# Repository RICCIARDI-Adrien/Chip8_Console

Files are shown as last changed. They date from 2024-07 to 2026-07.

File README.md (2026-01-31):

# Chip-8 Console

A Chip-8/SuperChip-8 console powered by a 8-bit PIC18 microcontroller.

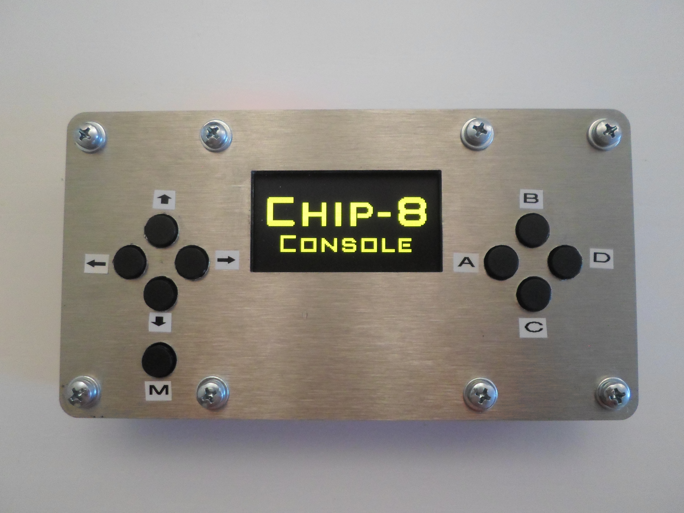
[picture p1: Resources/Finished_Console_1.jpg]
Console displaying the boot logo


## Specifications

* Microchip PIC18F27K42 8-bit microcontroller
* 64 MHz, giving a processing speed of up to 16 MIPS
* 8 KB of on-chip static RAM
* 128x64 pixels monochrome OLED display (Waveshare 2.42inch OLED Display Module)
* SD card interface to store games and files
* Powered by 2x AA batteries
* 8 keys usable with the Chip-8 interpreter, 1 menu key, 1 power-supply switch
* Monotone buzzer

## Dimensions

* Length : 175 mm
* Width : 95 mm
* Depth : 38 mm (including the adhesive feet)
* Weight : 1200 g (including the batteries and the SD card)

## Hardware

Display module :
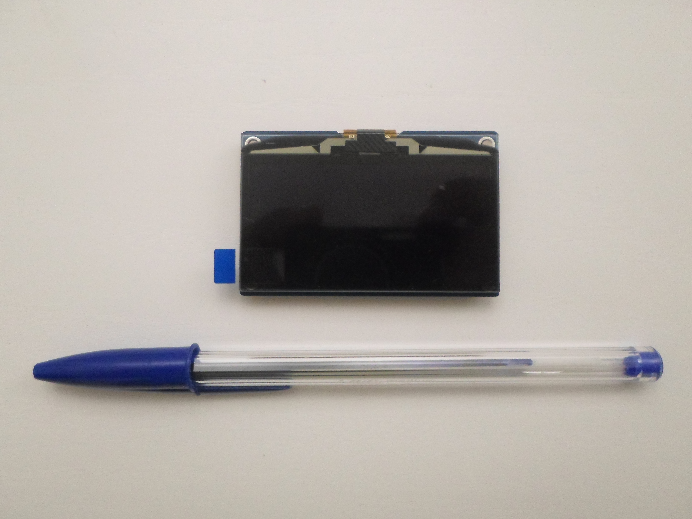
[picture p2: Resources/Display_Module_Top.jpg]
Display module front view

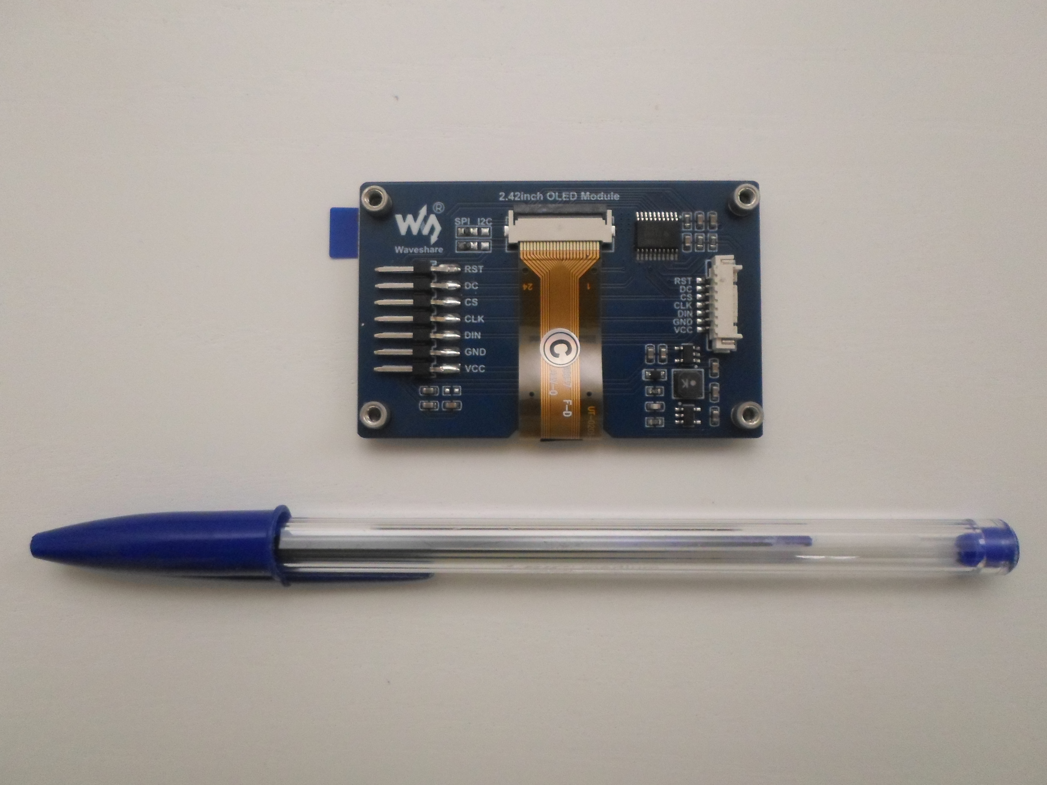
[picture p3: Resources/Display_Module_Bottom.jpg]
Display module bottom view


Bare PCB :
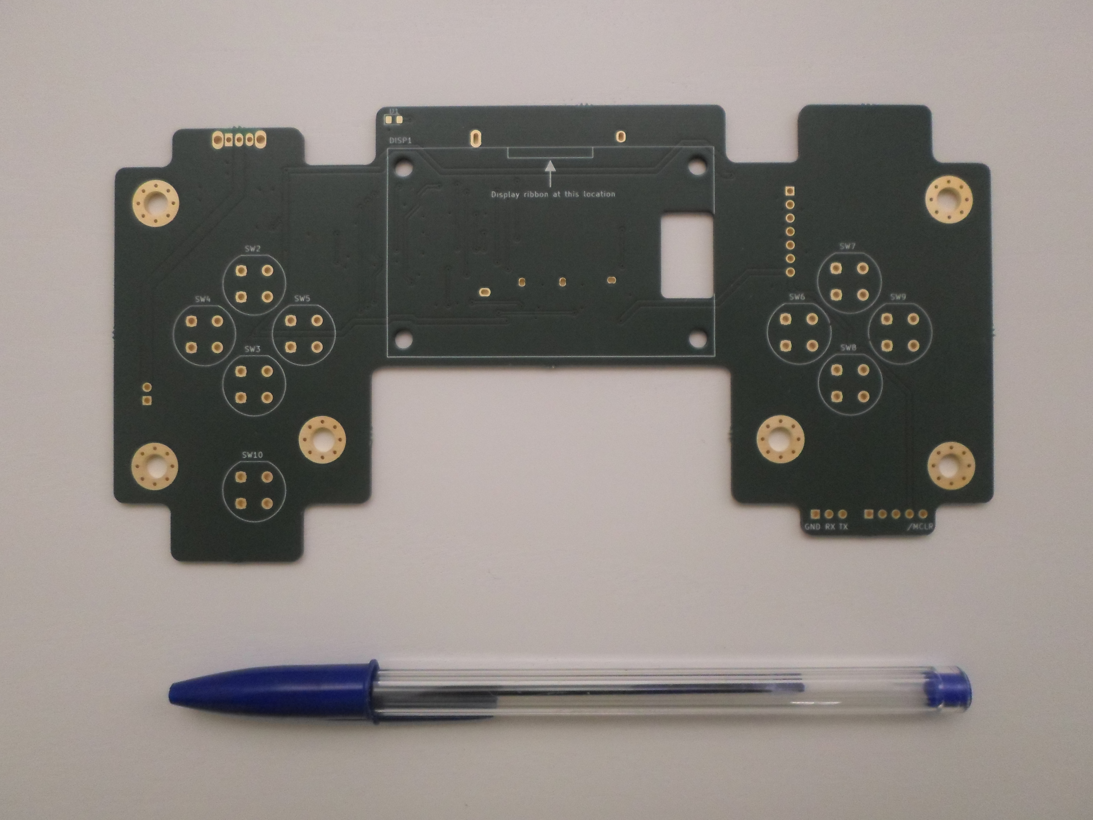
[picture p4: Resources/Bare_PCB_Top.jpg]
Bare PCB front view

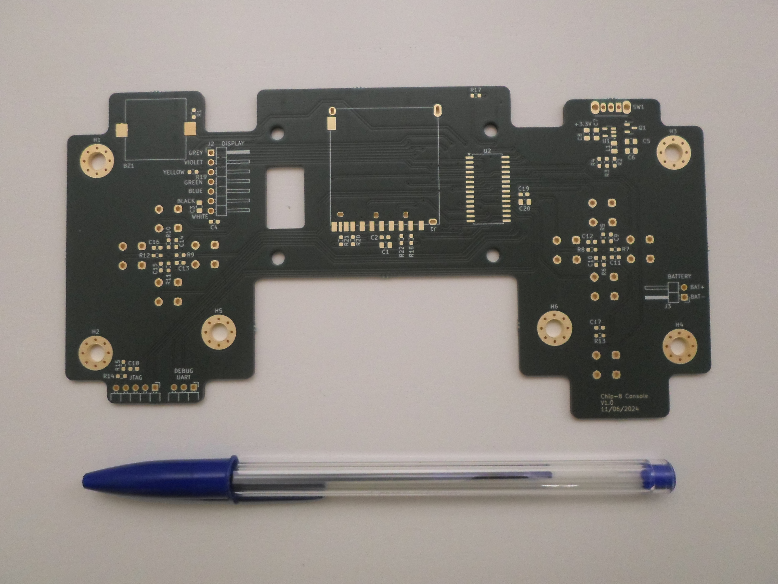
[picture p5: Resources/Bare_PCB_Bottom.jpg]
Bare PCB bottom view


Assembled PCB :
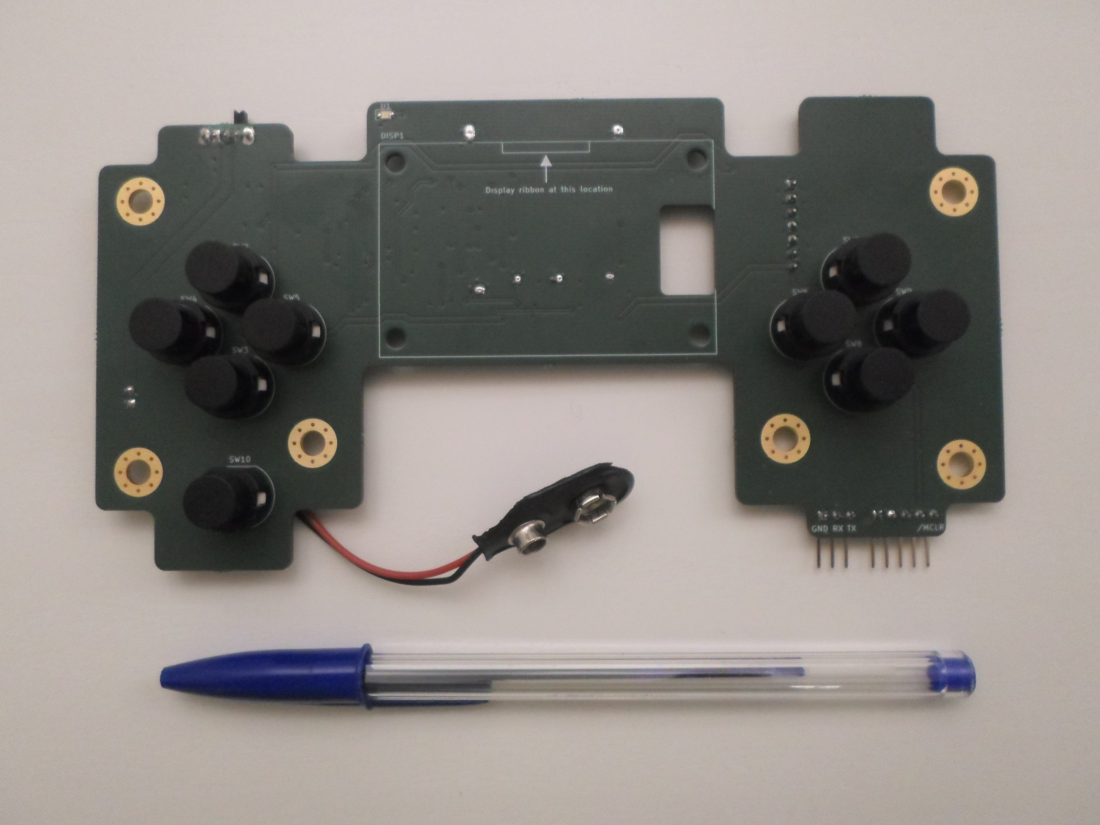
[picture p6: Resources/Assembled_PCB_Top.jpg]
Assembled PCB front view

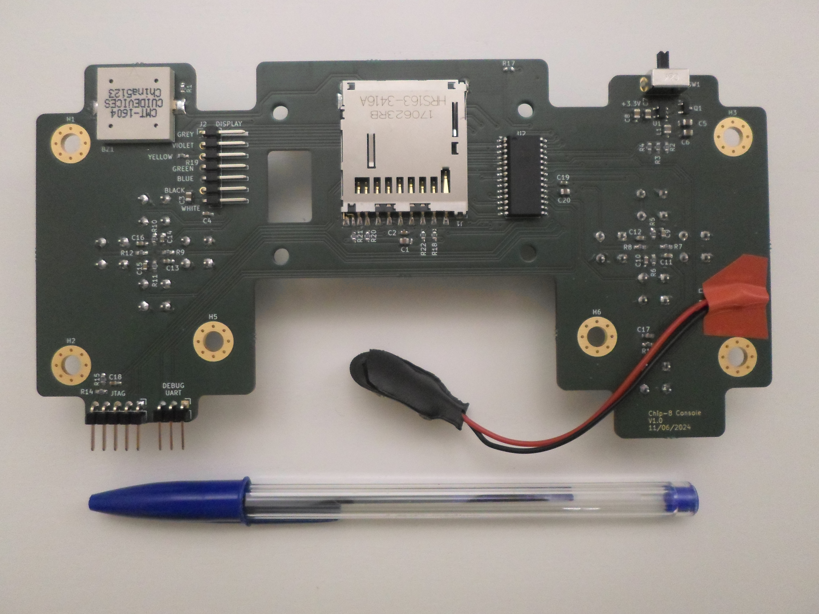
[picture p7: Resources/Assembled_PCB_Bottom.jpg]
Assembled PCB bottom view


Assembled PCB with the display module screwed and connected :
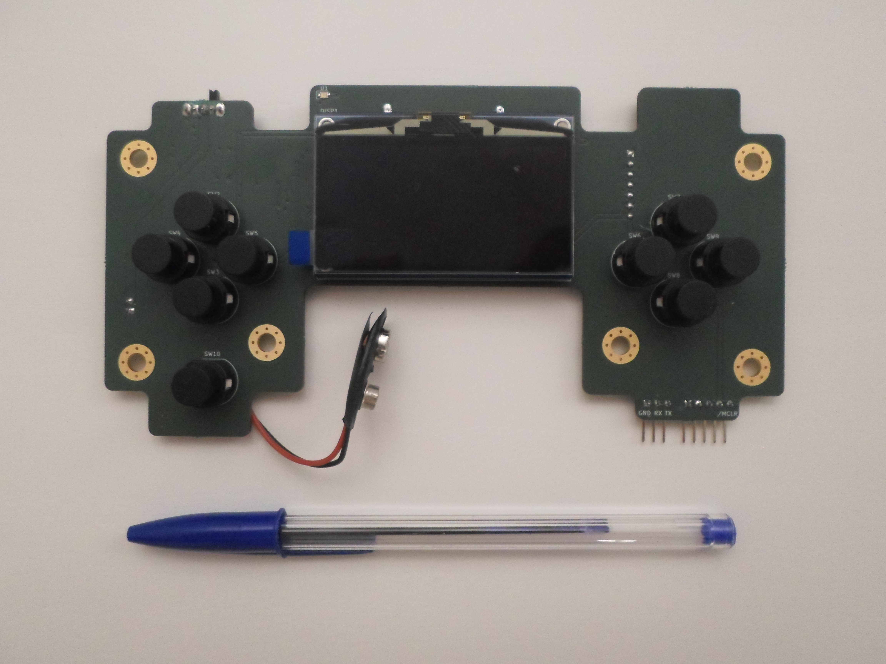
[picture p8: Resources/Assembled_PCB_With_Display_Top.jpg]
Assembled PCB with display front view

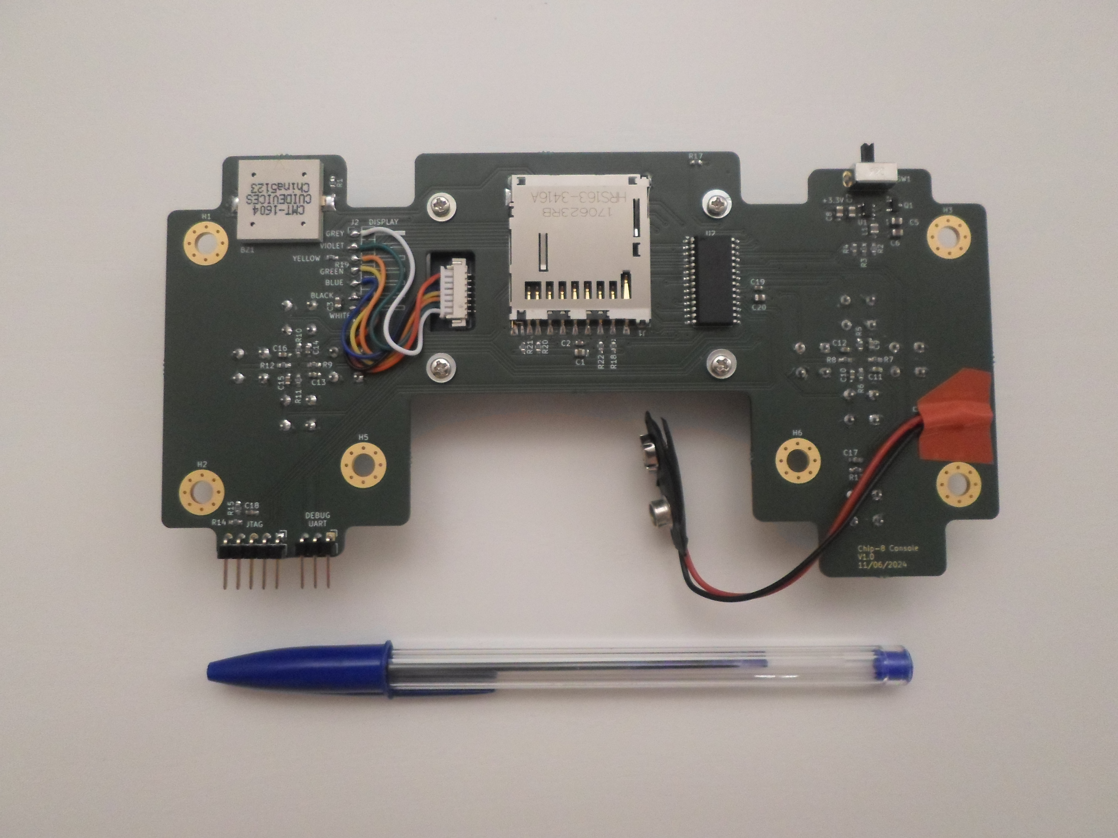
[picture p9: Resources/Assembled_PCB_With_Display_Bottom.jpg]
Assembled PCB with display bottom view


## Casing

The casing is made of two laser-cut metal plates. They are both 4 mm thick and made of stainless 304 steel.  
The metal spacers are 20 mm high. The reference used here is `970200471` from Würth Elektronik.  

Casing plates :
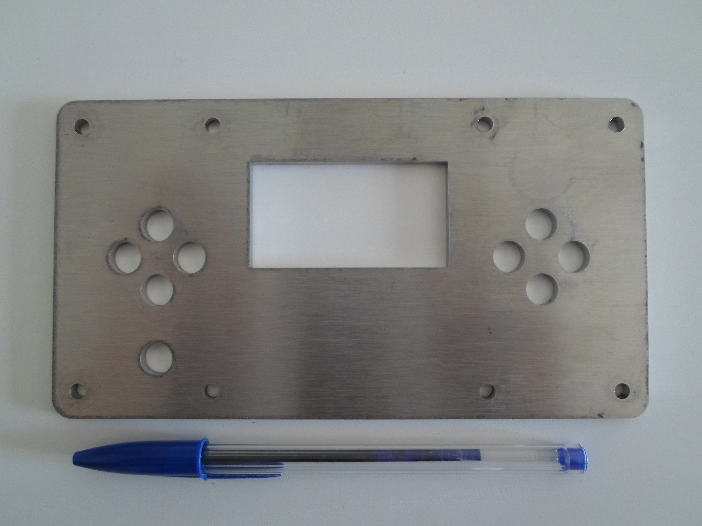
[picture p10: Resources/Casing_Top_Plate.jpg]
Casing top plate

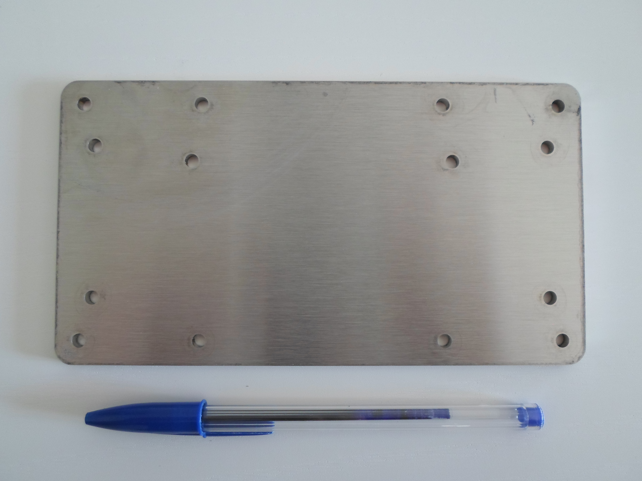
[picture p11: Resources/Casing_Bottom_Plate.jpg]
Casing bottom plate


Bottom plate with screws :
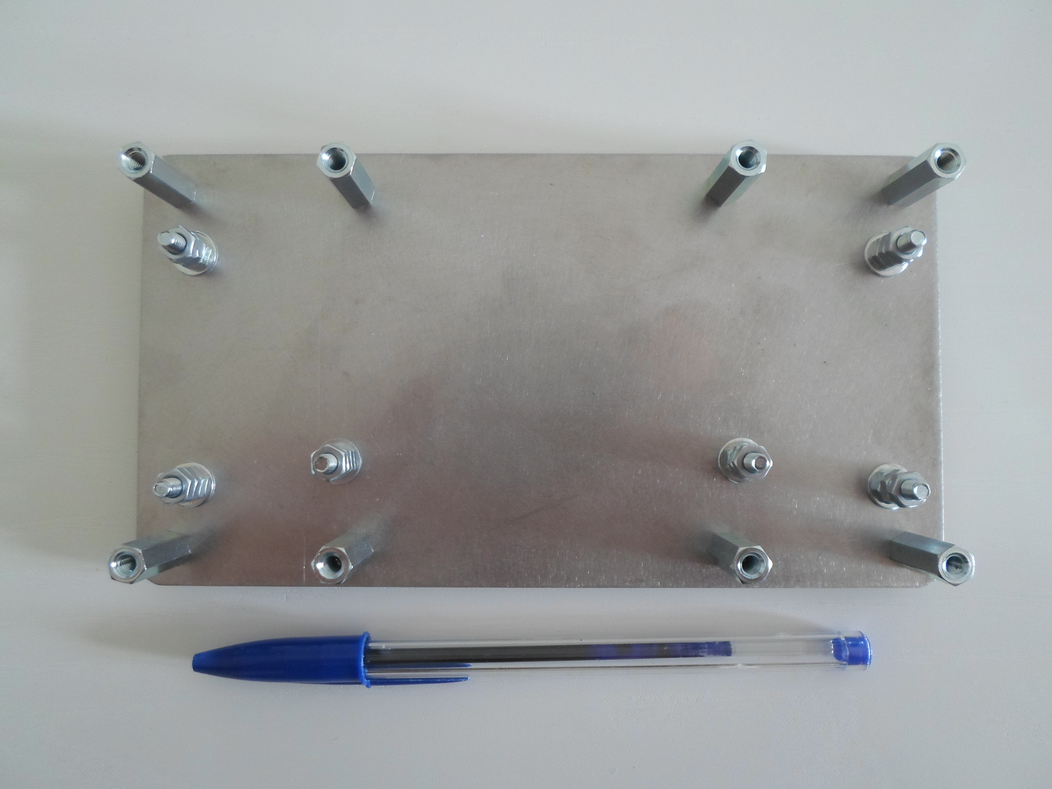
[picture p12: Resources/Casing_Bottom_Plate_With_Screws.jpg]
Casing bottom plate with screws


Bottom plate with screwed PCB :
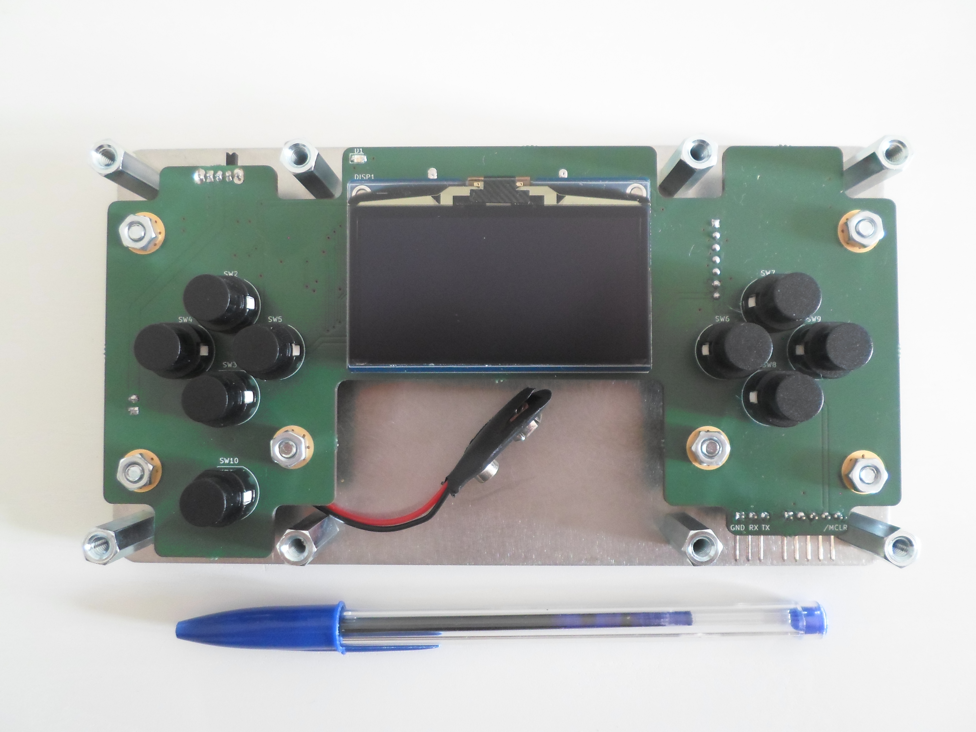
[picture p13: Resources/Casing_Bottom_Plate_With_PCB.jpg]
Casing bottom plate with PCB


Fully assembled console :
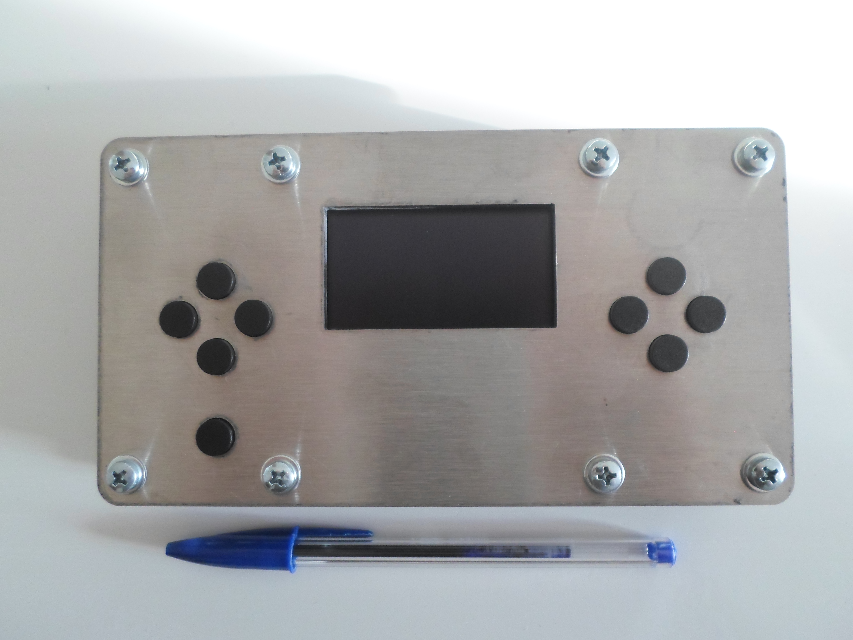
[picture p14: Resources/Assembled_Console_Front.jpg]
Assembled console front

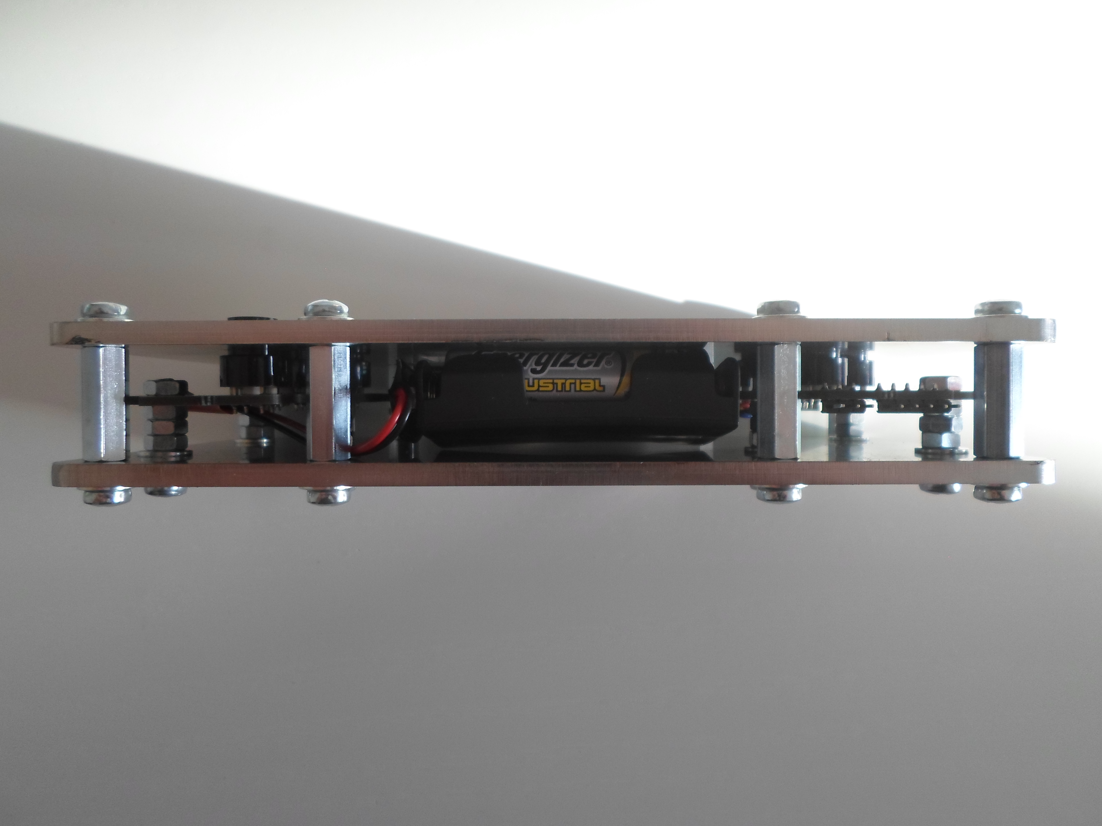
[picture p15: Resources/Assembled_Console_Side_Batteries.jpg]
Assembled console batteries side


## Battery pack hatch

The hatch is made of PCB FR4. The hatch does not require to be as strong as the console casing and the FR4 is a good material to cut complex shapes into.

The hatch is cut as a PCB panel containing all the required parts :
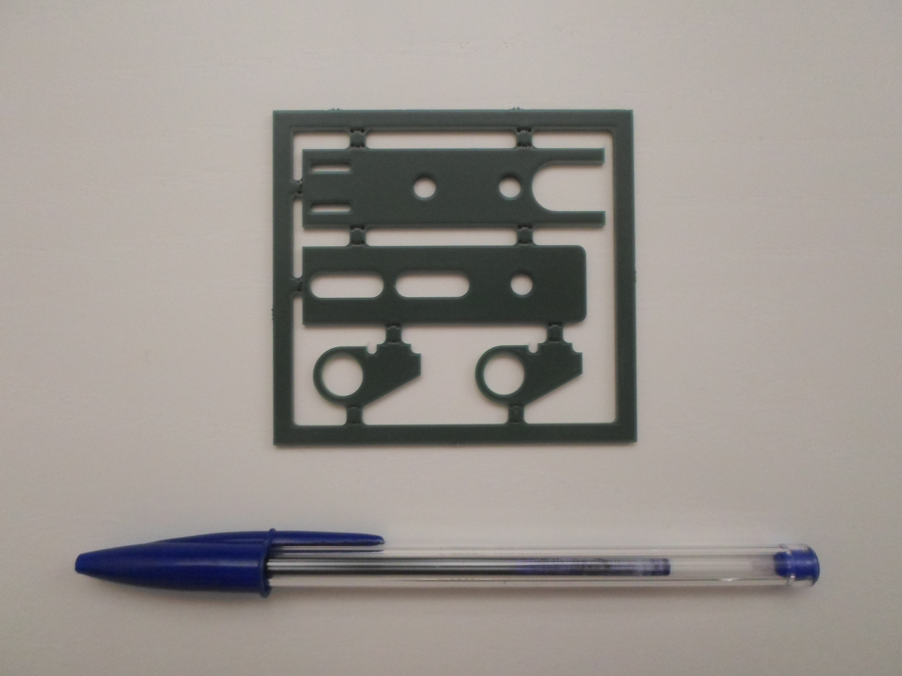
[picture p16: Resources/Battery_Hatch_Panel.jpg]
Battery hatch panel


The first assembly step is to glue the hinges :
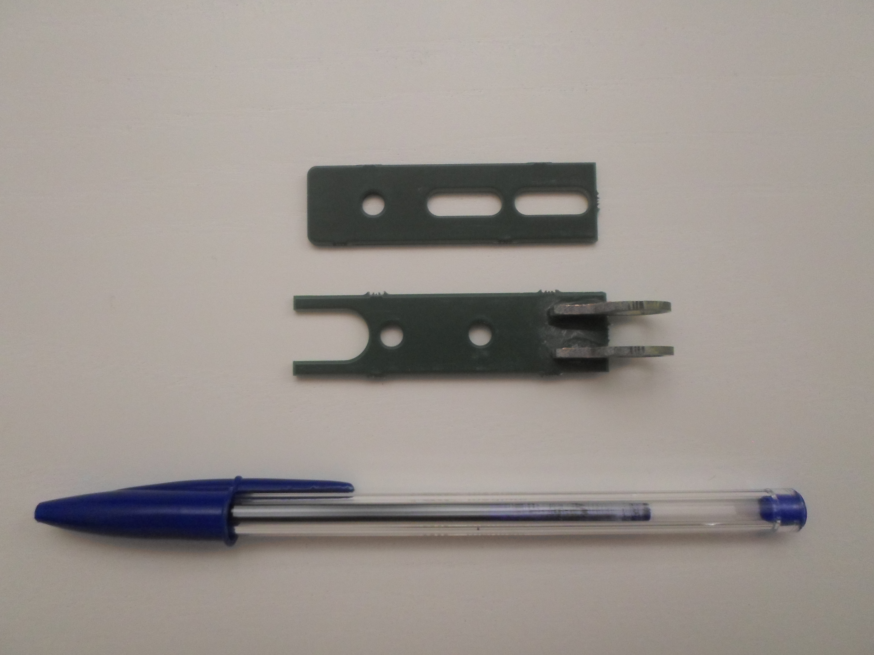
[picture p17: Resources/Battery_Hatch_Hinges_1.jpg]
Battery hatch hinges 1

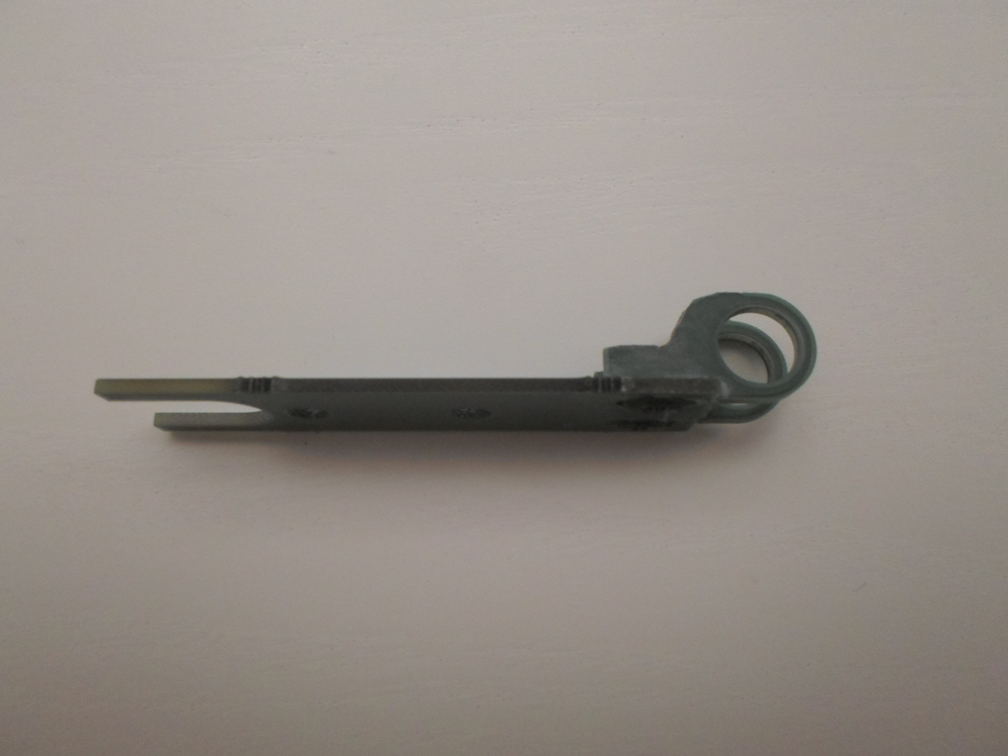
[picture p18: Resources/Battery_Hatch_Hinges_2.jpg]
Battery hatch hinges 2

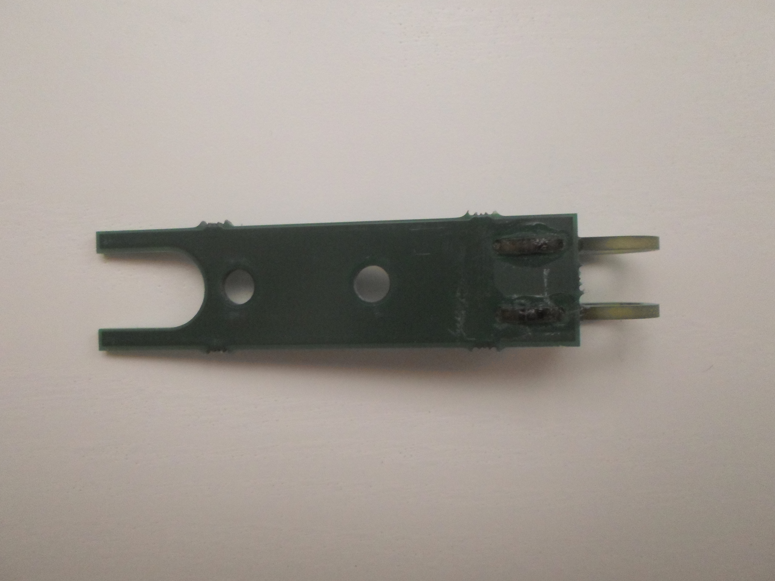
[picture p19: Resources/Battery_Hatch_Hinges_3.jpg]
Battery hatch hinges 3

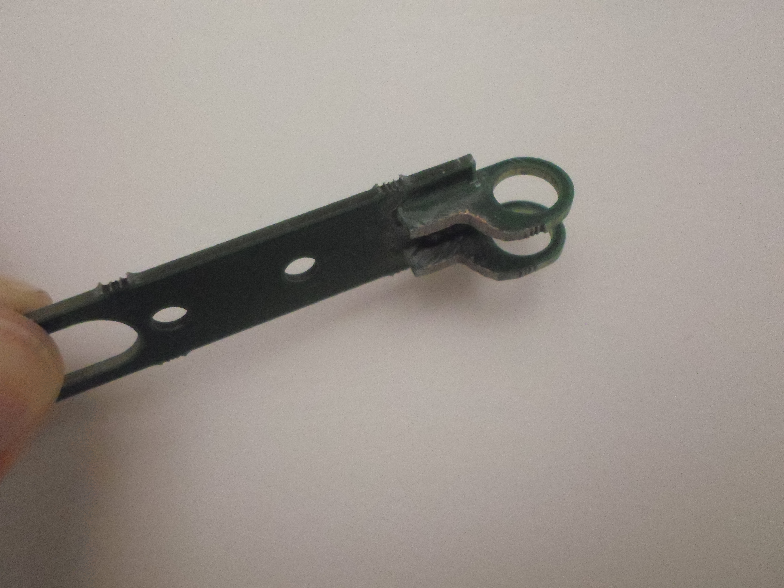
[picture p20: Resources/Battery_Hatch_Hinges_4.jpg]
Battery hatch hinges 4


The second step is to screw the sliding part, and also the bolt used to manipulate the hatch slider :
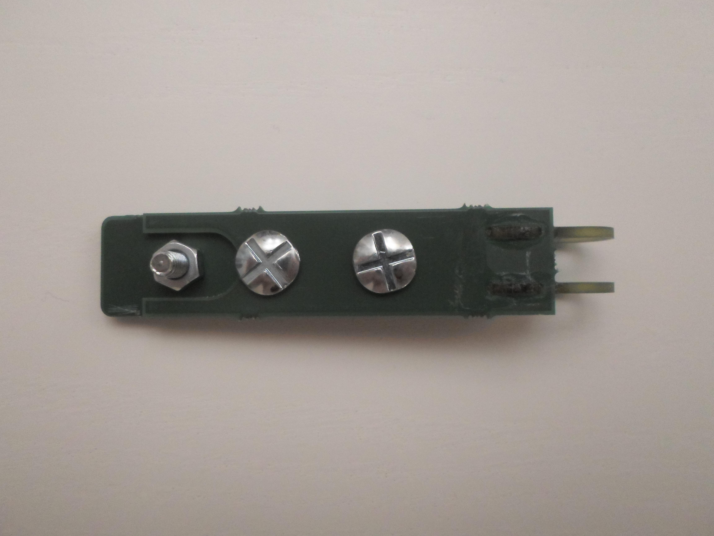
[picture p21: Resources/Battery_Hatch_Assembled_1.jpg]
Battery hatch assembled 1

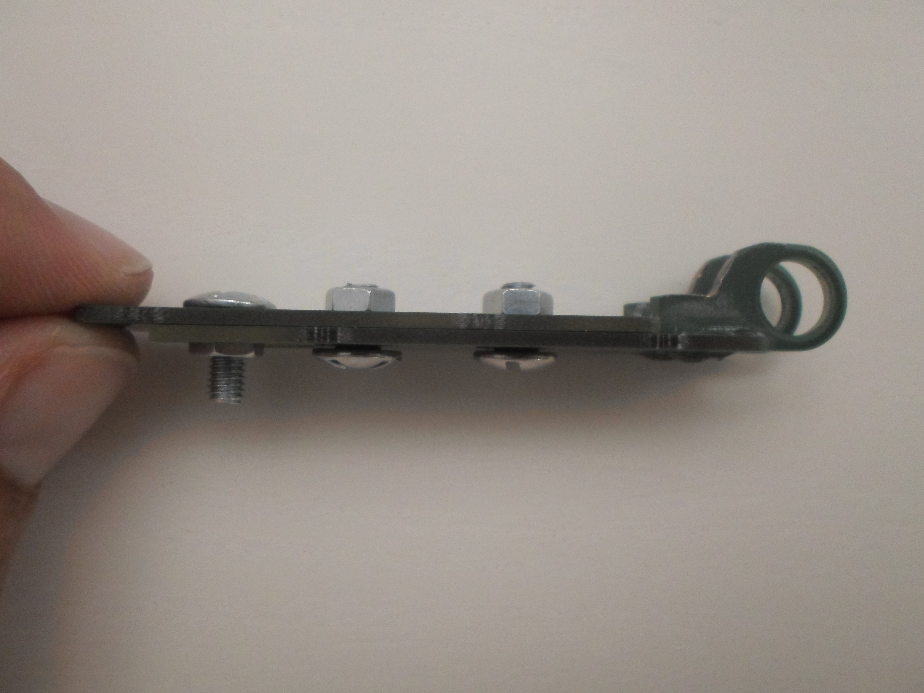
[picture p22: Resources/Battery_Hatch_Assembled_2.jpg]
Battery hatch assembled 2

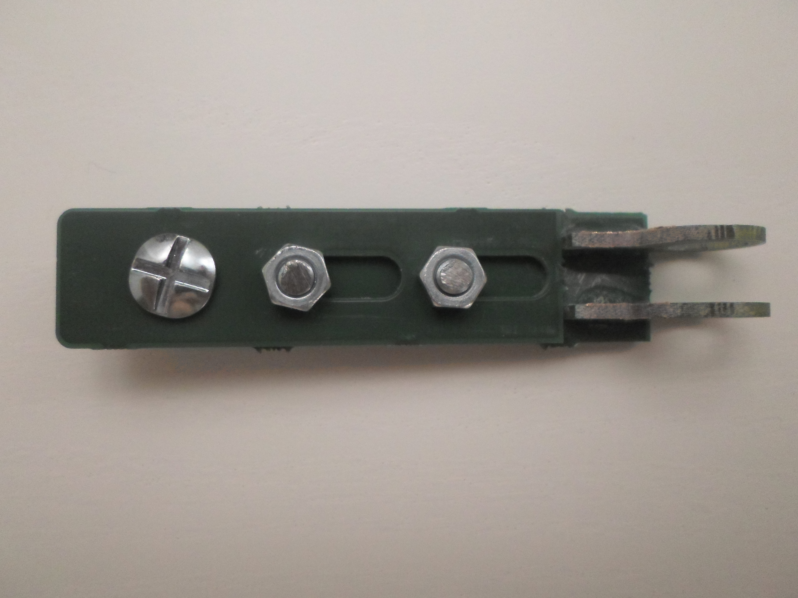
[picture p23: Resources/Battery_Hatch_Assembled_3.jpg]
Battery hatch assembled 3


There is not enough room to use Nyloc nuts, so normal nuts are used and held in place with threadlocker.  
The tightening of these bolts allows the slider to slide with a little force, so the hatch can't open alone.
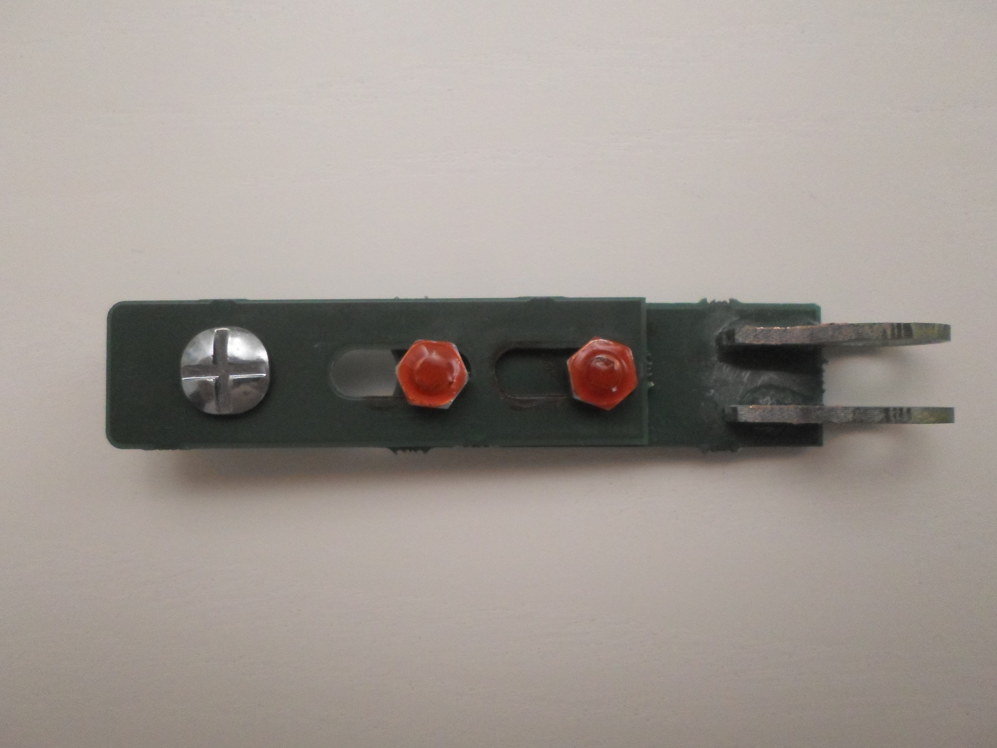
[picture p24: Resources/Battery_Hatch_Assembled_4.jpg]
Battery hatch assembled 4


The strike is made of a piece of PCB coming from the panel edge that is inserted by force between the two metal plates :
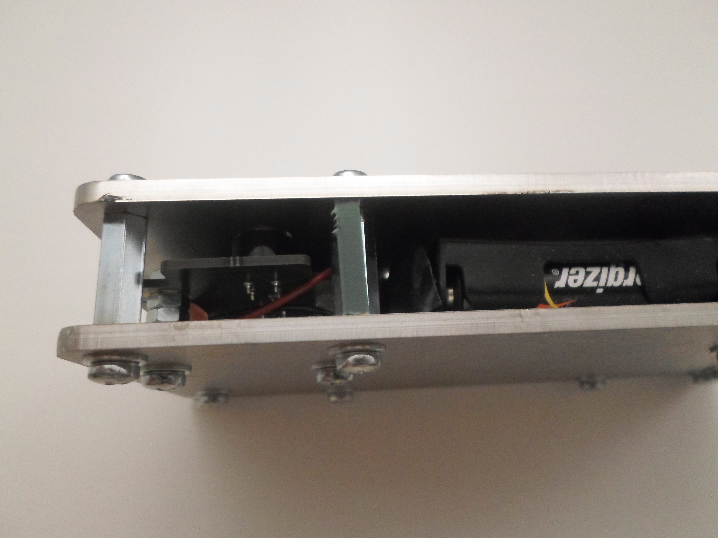
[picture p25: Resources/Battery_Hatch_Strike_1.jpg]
Battery hatch strike 1

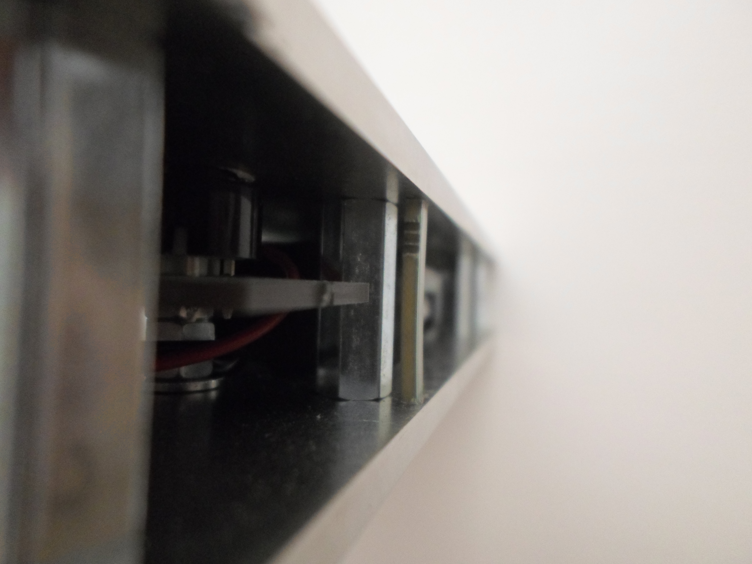
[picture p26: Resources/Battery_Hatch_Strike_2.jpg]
Battery hatch strike 2

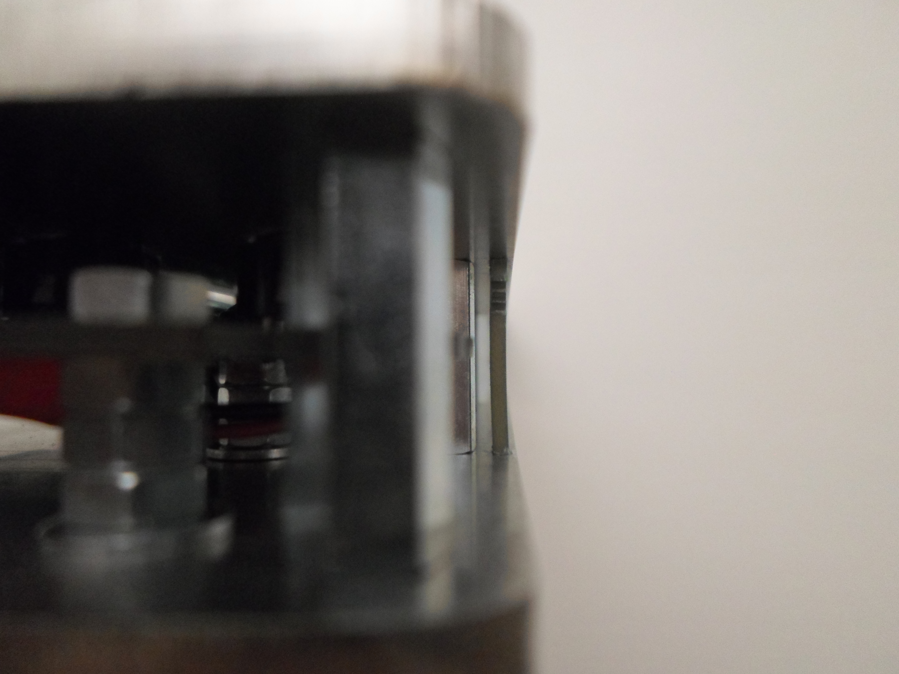
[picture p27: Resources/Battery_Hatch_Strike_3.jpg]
Battery hatch strike 3


Now the hatch can be assembled onto the console.  
Locked hatch :
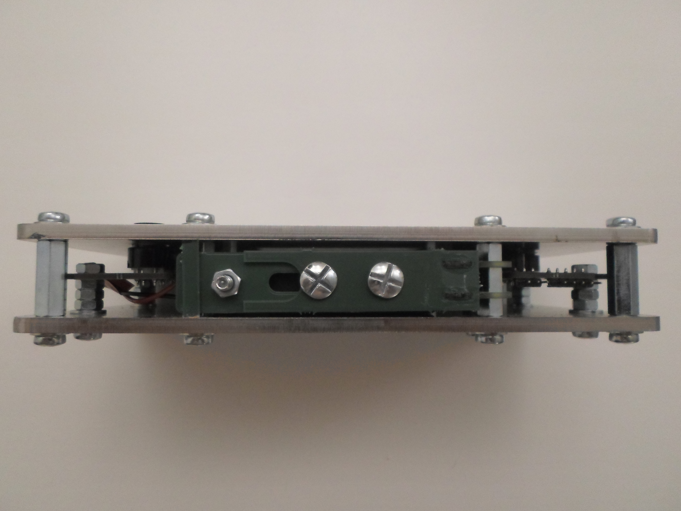
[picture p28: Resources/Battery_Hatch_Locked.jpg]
Battery hatch locked


Unlocked hatch :
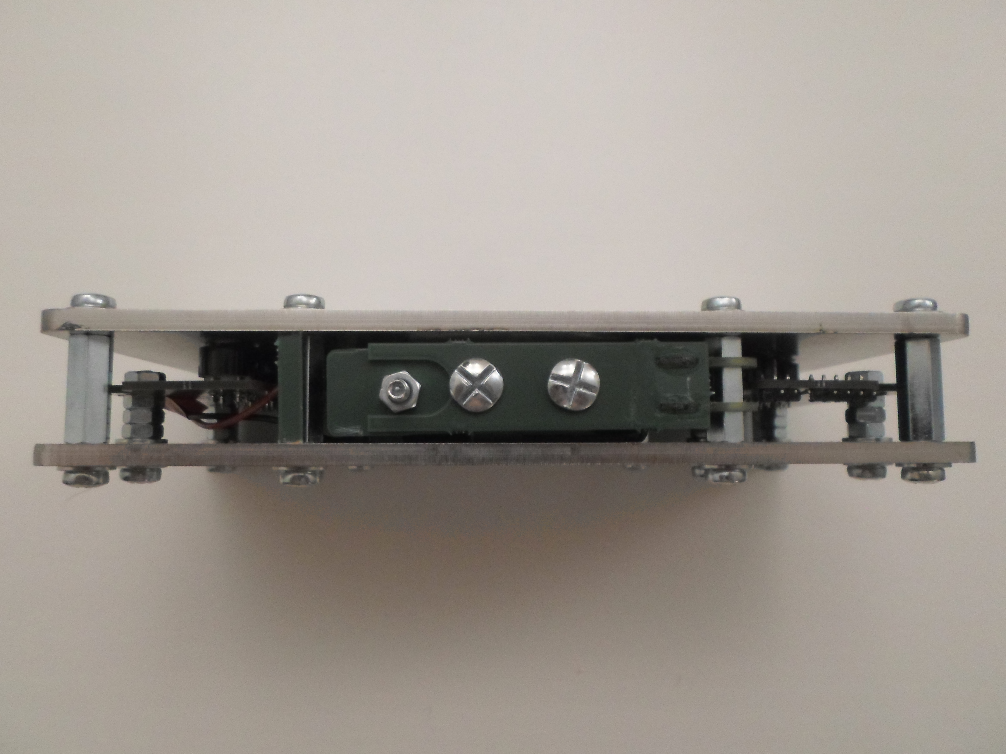
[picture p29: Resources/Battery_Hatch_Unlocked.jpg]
Battery hatch unlocked


Opened hatch :
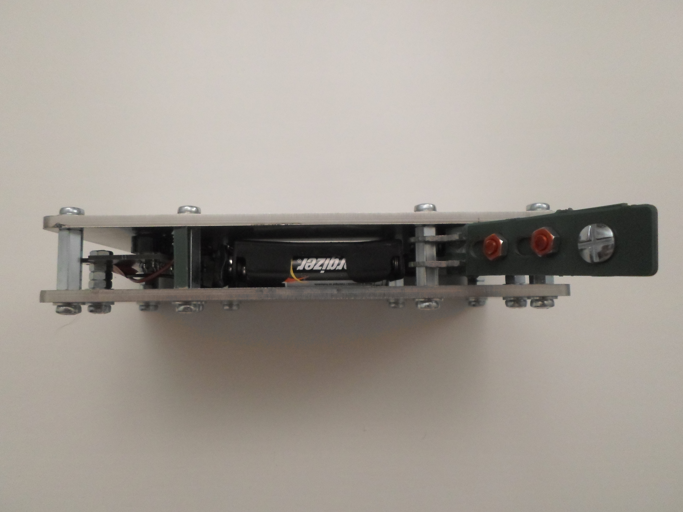
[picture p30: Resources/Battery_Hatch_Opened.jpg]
Battery hatch opened


## Photo gallery

The console boot logo :
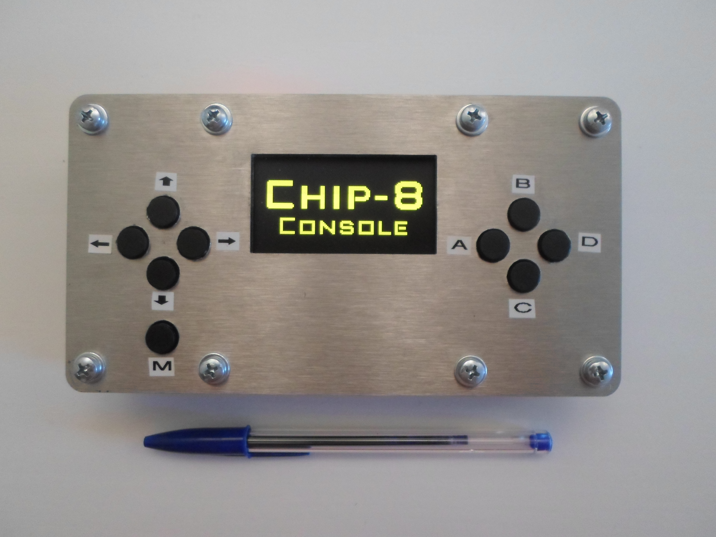
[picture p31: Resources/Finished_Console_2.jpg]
Console boot logo


Improved the PCB supports that were made of several nuts. The nuts did not had the same width, resulting in the PCB not being perfectly flat. The nuts have then been replaced by precise 10mm spacers :
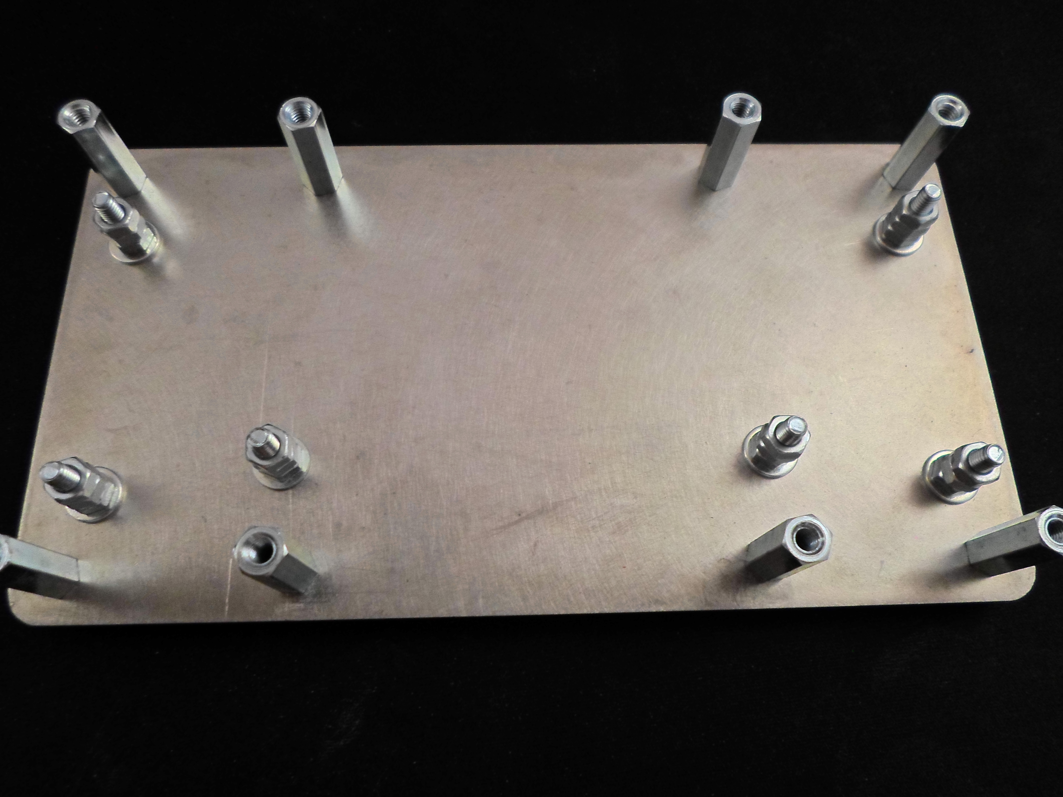
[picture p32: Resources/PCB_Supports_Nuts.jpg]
PCB supports with nuts

PCB supports with spacers

Improved the top plate button holes (using holes of 9.6mm diameter) :
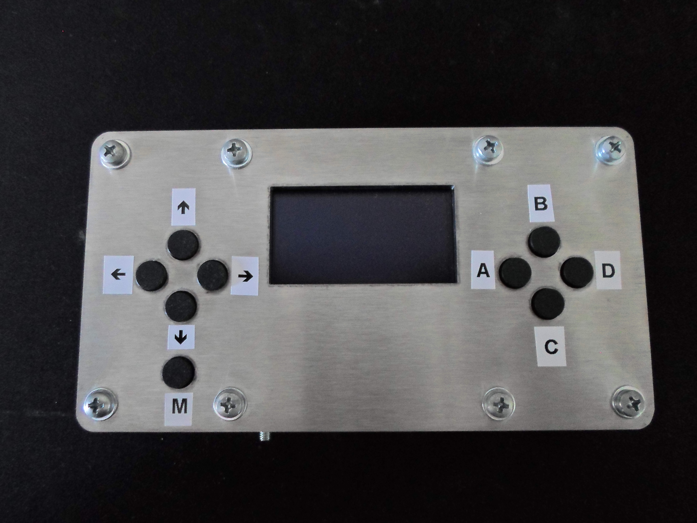
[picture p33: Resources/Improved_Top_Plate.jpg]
Improved top plate


The various console menus (as of firmware `V1.1`) :
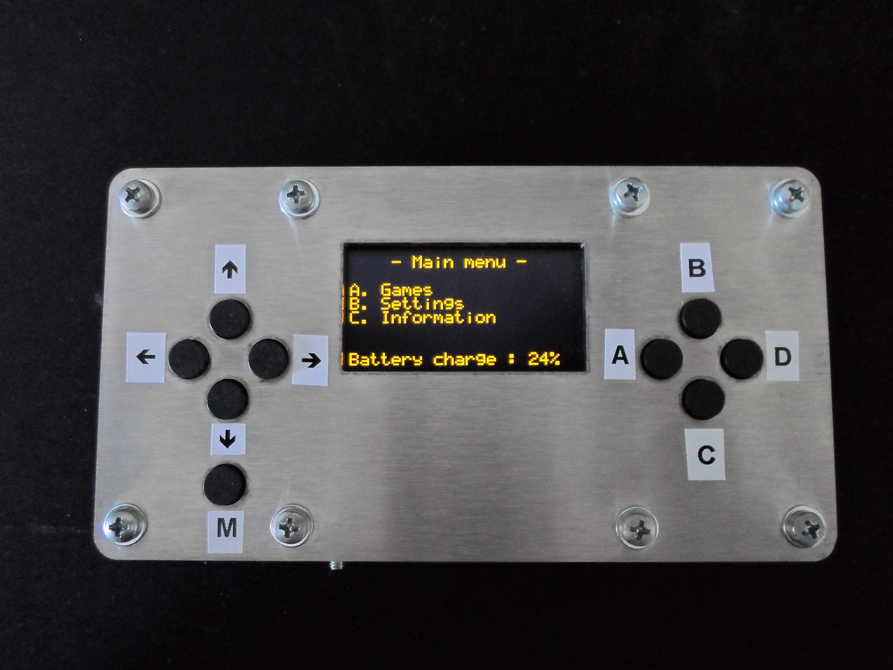
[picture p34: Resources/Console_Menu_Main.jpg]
Console main menu

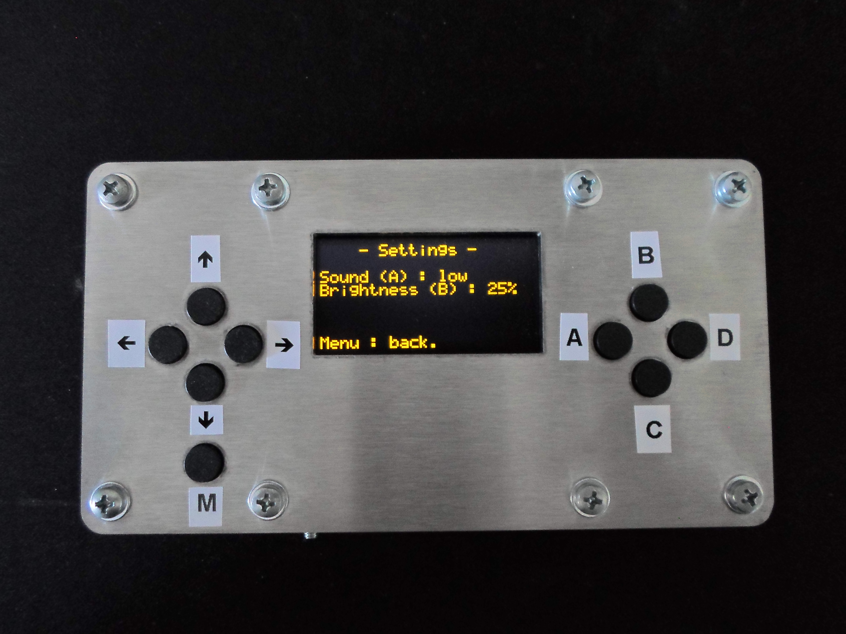
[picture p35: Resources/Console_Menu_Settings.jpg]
Console settings menu

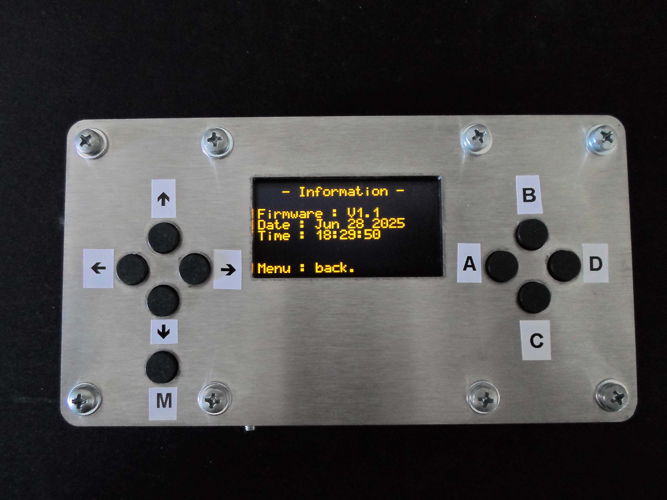
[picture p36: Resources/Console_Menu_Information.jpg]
Console information menu


Playing some video games :  
*3D VIP'r Maze* :
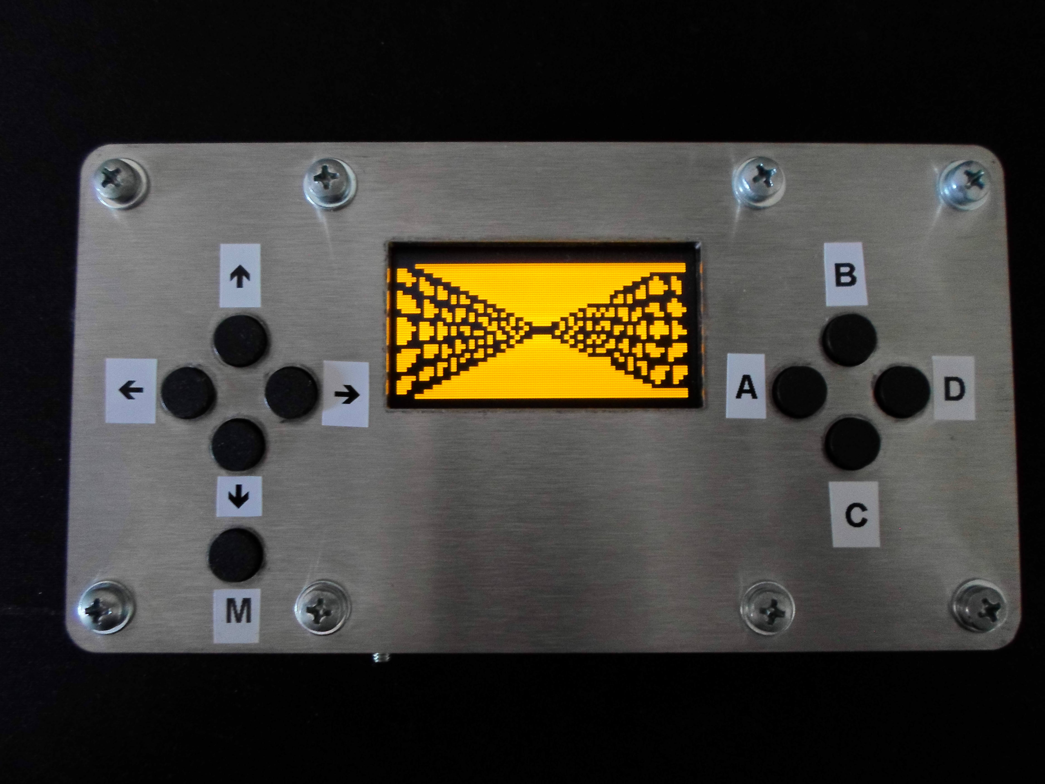
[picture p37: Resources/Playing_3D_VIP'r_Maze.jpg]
Playing 3D VIP'r Maze

*Ant* :
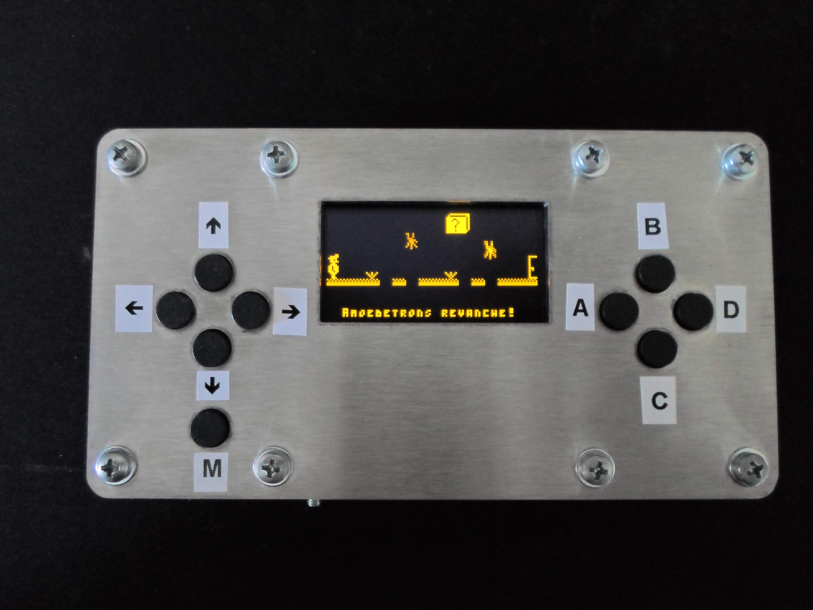
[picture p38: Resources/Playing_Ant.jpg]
Playing Ant

*Glitch Ghost* :
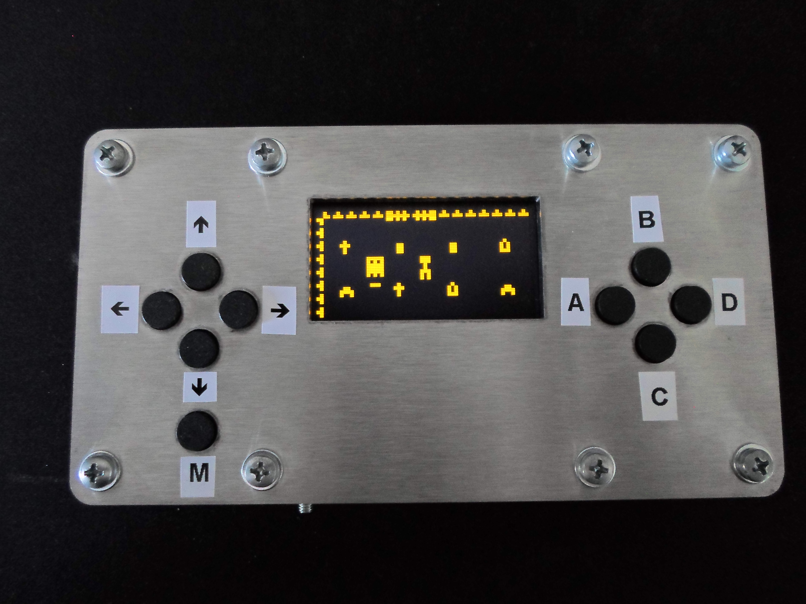
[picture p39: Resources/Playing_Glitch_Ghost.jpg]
Playing Glitch Ghost


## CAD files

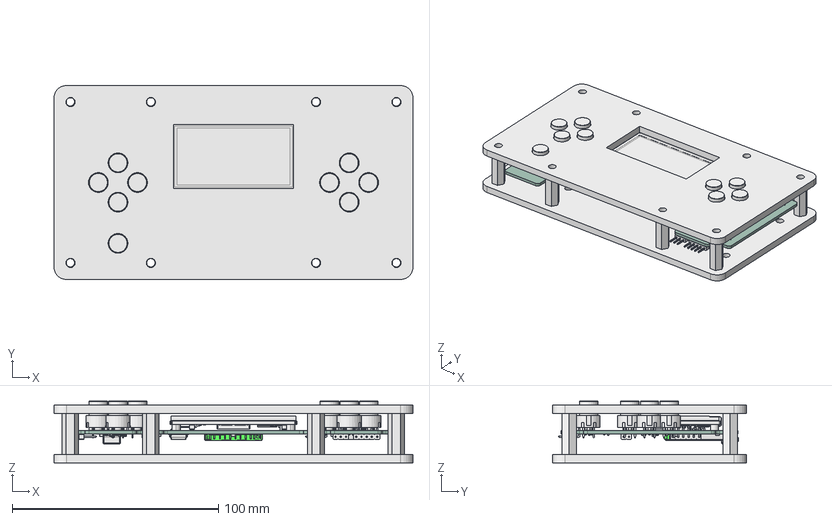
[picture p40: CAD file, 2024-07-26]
Casing/Casing.FCStd
174.0 x 94.0 x 30.0 mm
C_0603_1608Metric
C_0603_1608Metric002
DM1B-DSF-PEJ
R_0603_1608Metric
R_0603_1608Metric002
R_0603_1608Metric004
C_0603_1608Metric004
C_0805_2012Metric
PinHeader_1x02_P254mm_Horizontal
R_0603_1608Metric006
SOT_23_5
R_0603_1608Metric008
C_0603_1608Metric006
C_0603_1608Metric008
R_0603_1608Metric010
SW_Slide_SPDT_Angled_CK_OS102011MA1Q
R_0603_1608Metric012
C_0603_1608Metric010
C_0805_2012Metric002
R_0603_1608Metric014
CUI_DEVICES_CMT-1604-SMT-TR
PinHeader_1x03_P254mm_Horizontal
R_0603_1608Metric016
R_0603_1608Metric018
SOT_23
R_0603_1608Metric020
C_0805_2012Metric004
C_0603_1608Metric012
C_0603_1608Metric014
C_0805_2012Metric006
PinHeader_1x07_P254mm_Horizontal
R_0603_1608Metric022
R_0603_1608Metric024
SOIC_28W_75x179mm_P127mm
C_0603_1608Metric016
C_0805_2012Metric008
R_0603_1608Metric026
R_0603_1608Metric028
C_0603_1608Metric018
C_0805_2012Metric010
PinHeader_1x05_P254mm_Horizontal
C_0603_1608Metric020
R_0603_1608Metric030
R_0603_1608Metric032
R_0603_1608Metric034
L_0805_2012Metric
C_0603_1608Metric022
C_0805_2012Metric012
R_0603_1608Metric036
C_0603_1608Metric024
R_0603_1608Metric038
R_0603_1608Metric040
D6R90F1LFS
D6R90F1LFS001
D6R90F1LFS002
LED_0805_2012Metric
D6R90F1LFS003
D6R90F1LFS004
D6R90F1LFS005
D6R90F1LFS006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

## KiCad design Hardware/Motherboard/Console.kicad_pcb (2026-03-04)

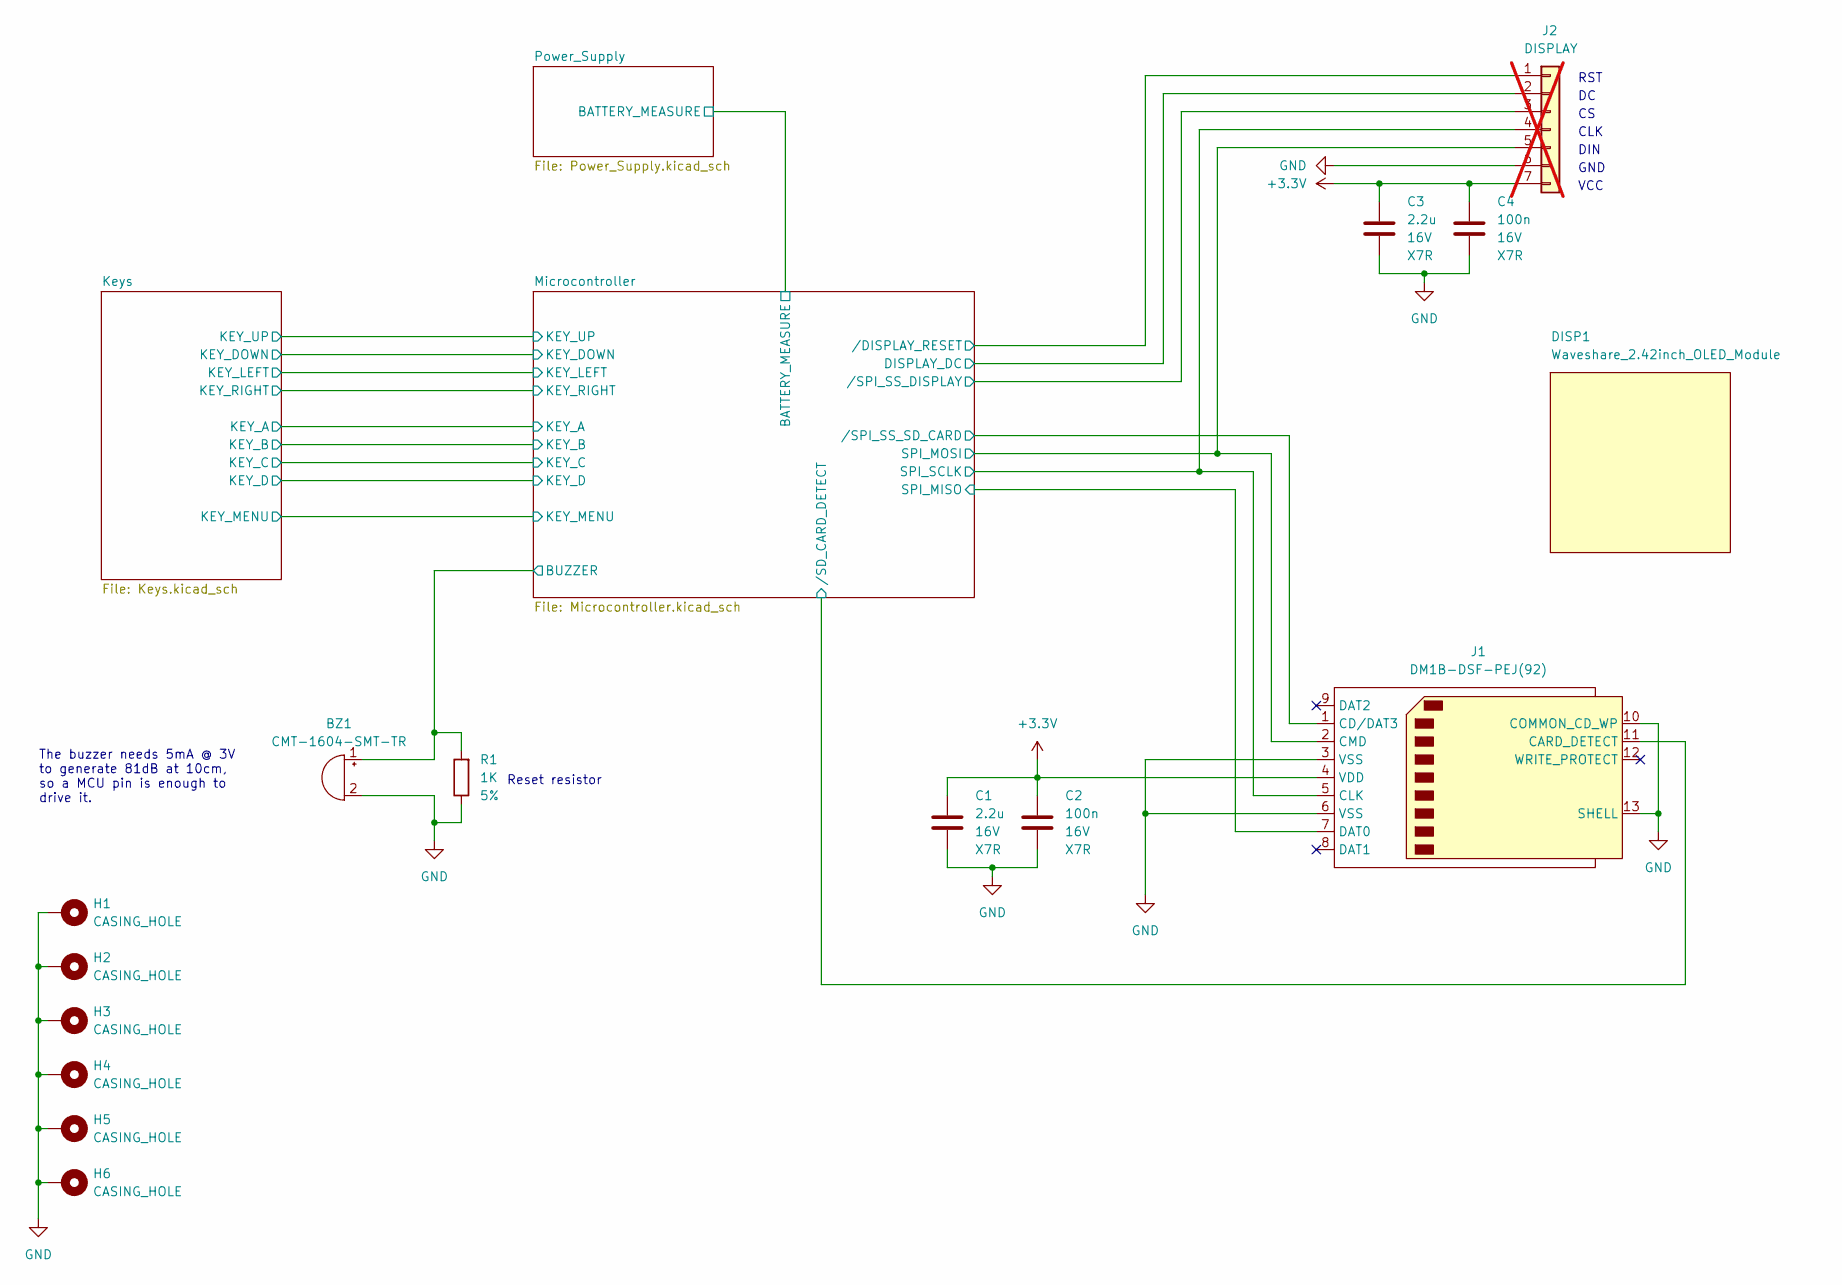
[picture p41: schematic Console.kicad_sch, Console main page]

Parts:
BZ1: CMT-1604-SMT-TR
C1, C3: 2.2u; C_0805_2012Metric_Pad1.18x1.45mm_HandSolder
C2, C4: 100n; C_0603_1608Metric_Pad1.08x0.95mm_HandSolder
DISP1: Waveshare_2.42inch_OLED_Module; 2.42inch_OLED_Module
H1, H2, H3, H4, H5, H6: CASING_HOLE; MountingHole_4.5mm_Pad_Via
J1: DM1B-DSF-PEJ(92)
J2: DISPLAY; PinHeader_1x07_P2.54mm_Horizontal; not fitted
R1: 1K; R_0603_1608Metric_Pad0.98x0.95mm_HandSolder

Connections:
+3.3V: C1.1, C2.1, C3.1, C4.1, J1.4 (VDD), J2.7; also elsewhere on the board
/Microcontroller/BUZZER: BZ1.1 (+), R1.2; also elsewhere on the board
/Microcontroller/DISPLAY_DC: J2.2; also elsewhere on the board
/Microcontroller/SPI_MISO: J1.7 (DAT0); also elsewhere on the board
/Microcontroller/SPI_MOSI: J1.2 (CMD), J2.5; also elsewhere on the board
/Microcontroller/SPI_SCLK: J1.5 (CLK), J2.4; also elsewhere on the board
/Microcontroller//DISPLAY_RESET: J2.1; also elsewhere on the board
/Microcontroller//SD_CARD_DETECT: J1.11 (CARD_DETECT); also elsewhere on the board
/Microcontroller//SPI_SS_DISPLAY: J2.3; also elsewhere on the board
/Microcontroller//SPI_SS_SD_CARD: J1.1 (CD/DAT3); also elsewhere on the board
GND: BZ1.2 (-), C1.2, C2.2, C3.2, C4.2, H1.1, H2.1, H3.1, H4.1, H5.1, H6.1, J1.3 (VSS), J1.6 (VSS), J1.10 (COMMON_CD_WP), J1.13 (SHELL), J1.14 (SHELL), J1.15 (SHELL), J1.16 (SHELL), J1.17 (SHELL), J1.18 (SHELL), J2.6, R1.1; also elsewhere on the board

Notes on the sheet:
Reset resistor
RST
DIN
VCC
CLK
The buzzer needs 5mA @ 3V to generate 81dB at 10cm, so a MCU pin is enough to drive it.
GND

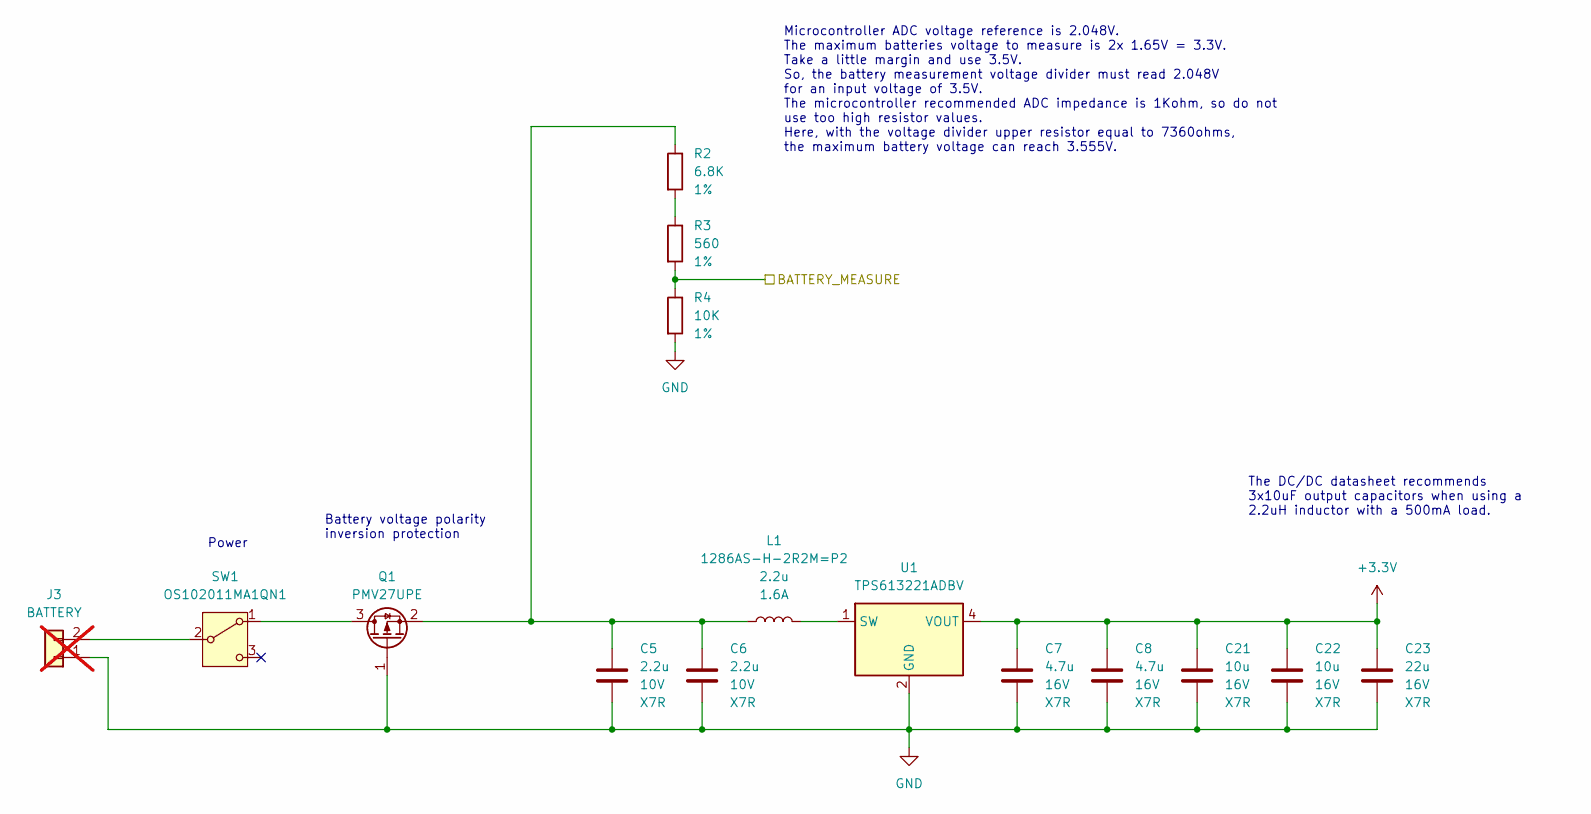
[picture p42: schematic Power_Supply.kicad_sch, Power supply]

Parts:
C5, C6: 2.2u; C_0805_2012Metric_Pad1.18x1.45mm_HandSolder
C7, C8: 4.7u; C_0805_2012Metric_Pad1.18x1.45mm_HandSolder
C21, C22: 10u; C_0805_2012Metric_Pad1.18x1.45mm_HandSolder
C23: 22u; C_1210_3225Metric_Pad1.33x2.70mm_HandSolder
J3: BATTERY; PinHeader_1x02_P2.54mm_Horizontal; not fitted
L1: 1286AS-H-2R2M=P2; 0806_HandSolder
Q1: PMV27UPE; SOT-23
R2: 6.8K; R_0603_1608Metric_Pad0.98x0.95mm_HandSolder
R3: 560; R_0603_1608Metric_Pad0.98x0.95mm_HandSolder
R4: 10K; R_0603_1608Metric_Pad0.98x0.95mm_HandSolder
SW1: OS102011MA1QN1; SW_Slide_SPDT_Angled_CK_OS102011MA1Q
U1: TPS613221ADBV; SOT-23-5

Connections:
+3.3V: C7.1, C8.1, C21.1, C22.1, C23.1, U1.4 (VOUT); also elsewhere on the board
/Microcontroller/BATTERY_MEASURE: R3.2, R4.1; also elsewhere on the board
GND: C5.2, C6.2, C7.2, C8.2, C21.2, C22.2, C23.2, J3.1, Q1.1 (G), R4.2, U1.2 (GND); also elsewhere on the board
unnamed: J3.2, SW1.2 (B)
unnamed: Q1.3 (D), SW1.1 (A)
unnamed: C5.1, C6.1, L1.1, Q1.2 (S), R2.1
unnamed: R2.2, R3.1
unnamed: L1.2, U1.1 (SW)

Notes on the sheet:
Microcontroller ADC voltage reference is 2.048V. The maximum batteries voltage to measure is 2x 1.65V = 3.3V. Take a little margin and use 3.5V. So, the battery measurement voltage divider must read 2.048V for an input voltage of 3.5V. The microcontroller recommended ADC impedance is 1Kohm, so do n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
The DC/DC datasheet recommends 3x10uF output capacitors when using a 2.2uH inductor with a 500mA load.
Power
Battery voltage polarity inversion protection

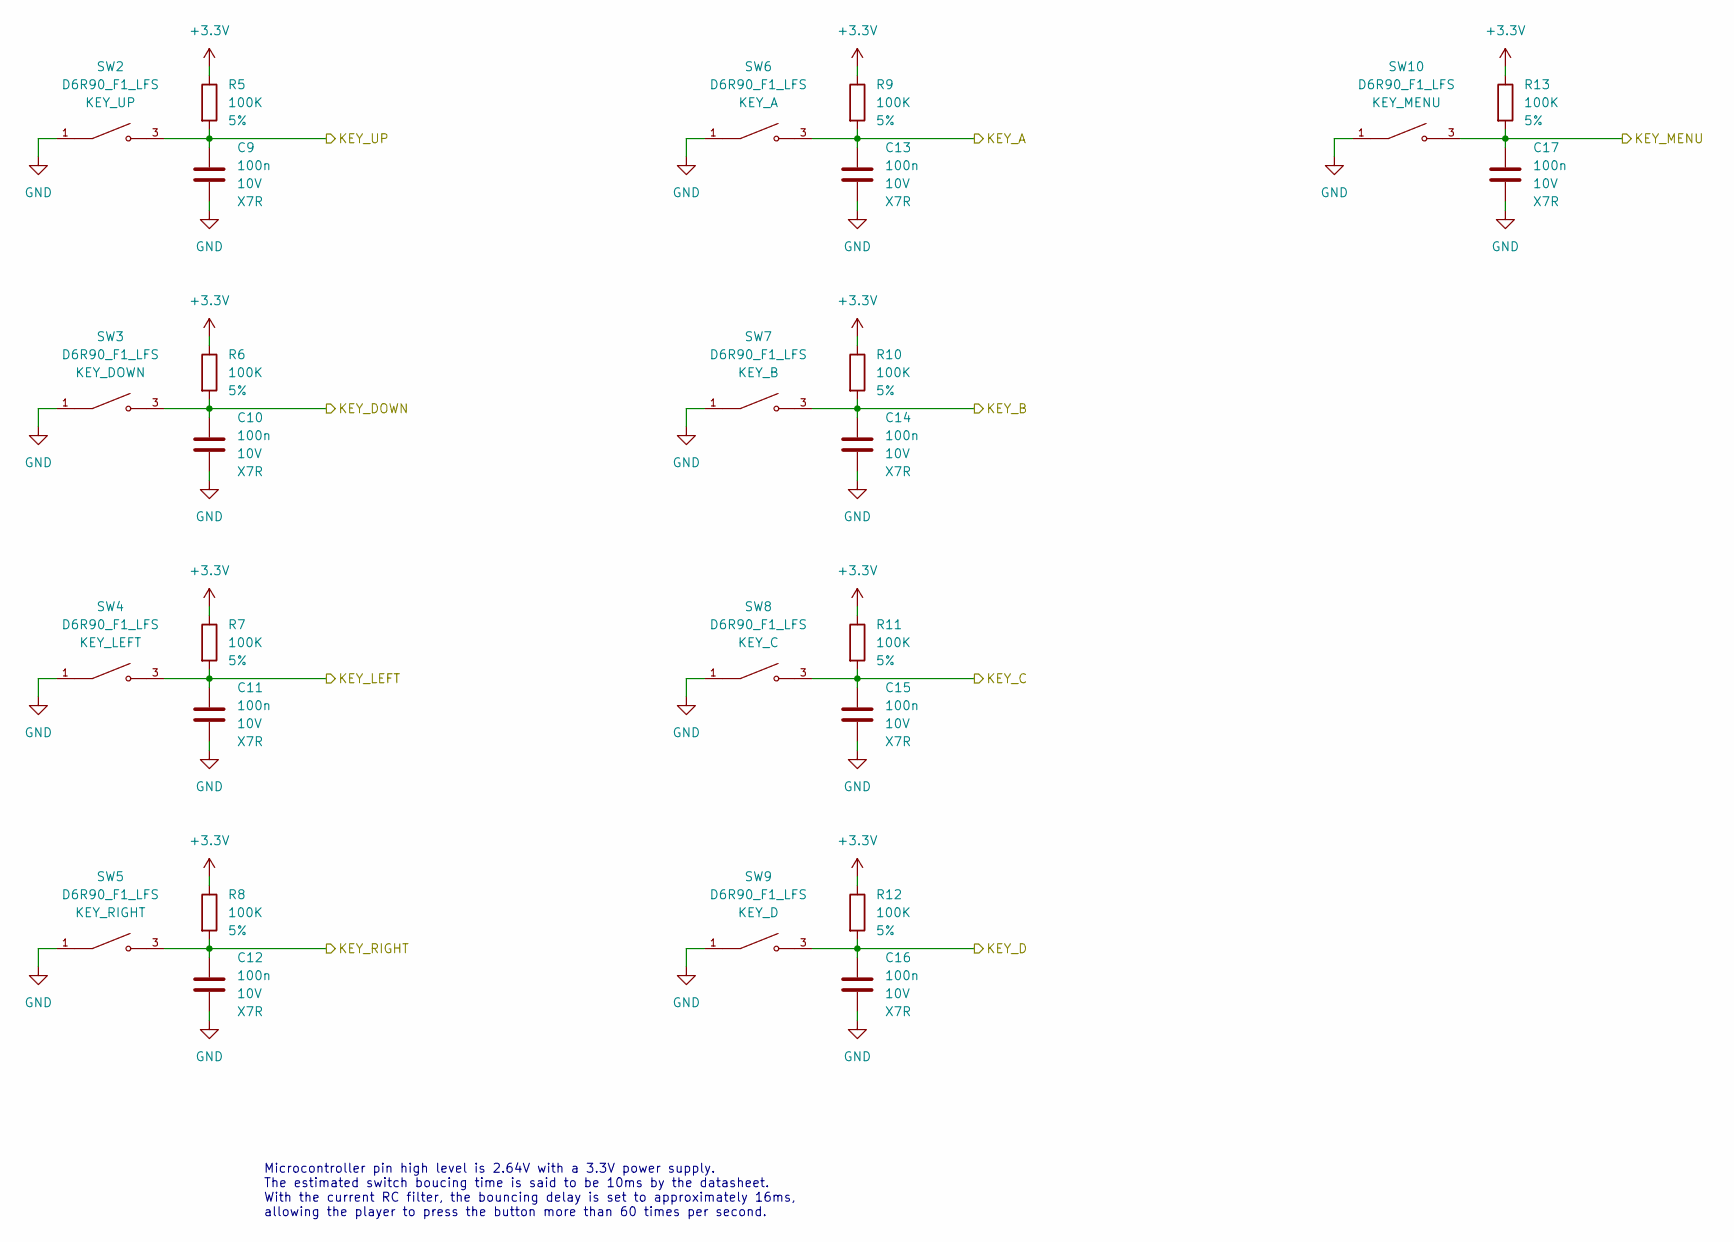
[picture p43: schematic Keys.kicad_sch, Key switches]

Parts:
C9, C10, C11, C12, C13, C14, C15, C16, C17: 100n; C_0603_1608Metric_Pad1.08x0.95mm_HandSolder
R5, R6, R7, R8, R9, R10, R11, R12, R13: 100K; R_0603_1608Metric_Pad0.98x0.95mm_HandSolder
SW2, SW3, SW4, SW5, SW6, SW7, SW8, SW9, SW10: D6R90_F1_LFS; SW_D6R90_F1_LFS

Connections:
+3.3V: R5.1, R6.1, R7.1, R8.1, R9.1, R10.1, R11.1, R12.1, R13.1; also elsewhere on the board
/Keys/KEY_A: C13.1, R9.2, SW6.3, SW6.4; also elsewhere on the board
/Keys/KEY_B: C14.1, R10.2, SW7.3, SW7.4; also elsewhere on the board
/Keys/KEY_C: C15.1, R11.2, SW8.3, SW8.4; also elsewhere on the board
/Keys/KEY_D: C16.1, R12.2, SW9.3, SW9.4; also elsewhere on the board
/Keys/KEY_DOWN: C10.1, R6.2, SW3.3, SW3.4; also elsewhere on the board
/Keys/KEY_LEFT: C11.1, R7.2, SW4.3, SW4.4; also elsewhere on the board
/Keys/KEY_MENU: C17.1, R13.2, SW10.3, SW10.4; also elsewhere on the board
/Keys/KEY_RIGHT: C12.1, R8.2, SW5.3, SW5.4; also elsewhere on the board
/Keys/KEY_UP: C9.1, R5.2, SW2.3, SW2.4; also elsewhere on the board
GND: C9.2, C10.2, C11.2, C12.2, C13.2, C14.2, C15.2, C16.2, C17.2, SW2.1, SW2.2, SW3.1, SW3.2, SW4.1, SW4.2, SW5.1, SW5.2, SW6.1, SW6.2, SW7.1, SW7.2, SW8.1, SW8.2, SW9.1, SW9.2, SW10.1, SW10.2; also elsewhere on the board

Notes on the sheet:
Microcontroller pin high level is 2.64V with a 3.3V power supply. The estimated switch boucing time is said to be 10ms by the datasheet. With the current RC filter, the bouncing delay is set to approximately 16ms, allowing the player to press the button more than 60 times per second.

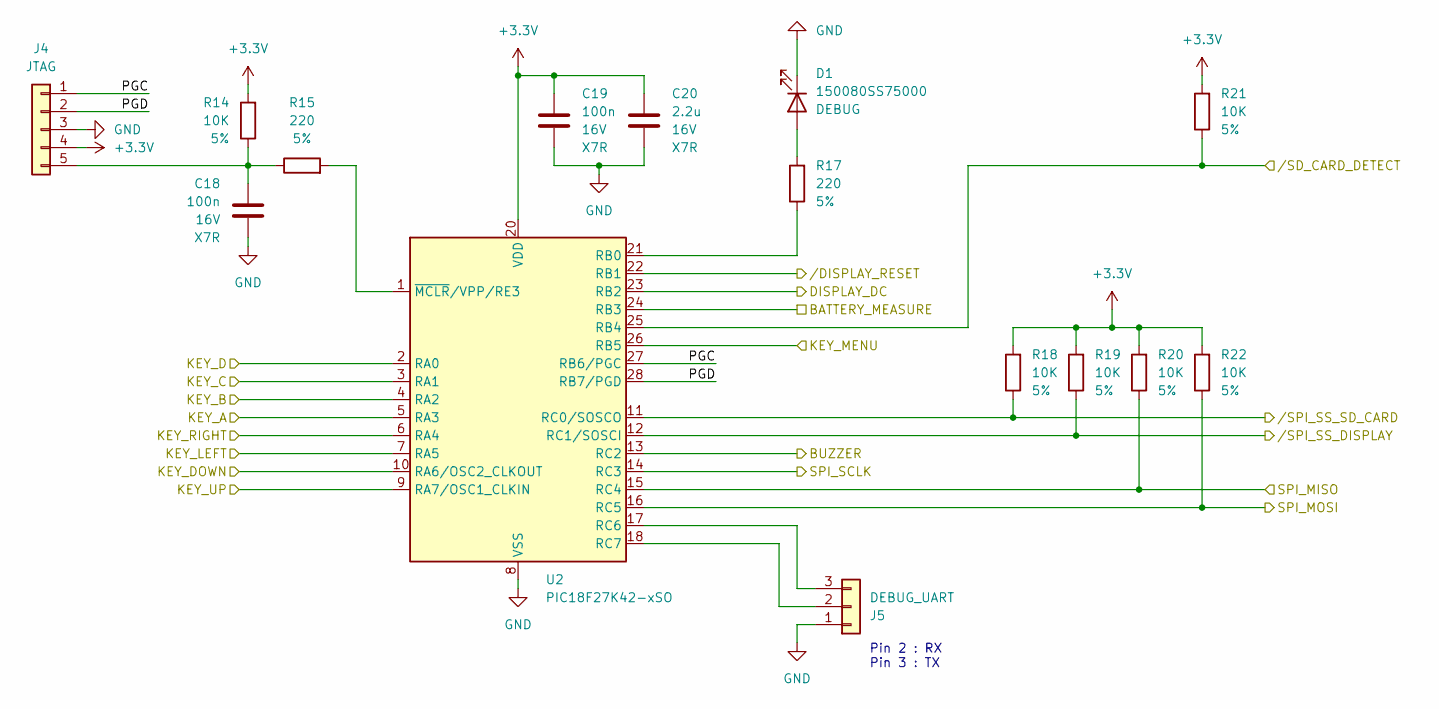
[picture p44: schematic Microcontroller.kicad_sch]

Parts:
C18, C19: 100n; C_0603_1608Metric_Pad1.08x0.95mm_HandSolder
C20: 2.2u; C_0805_2012Metric_Pad1.18x1.45mm_HandSolder
D1: 150080SS75000; LED_0805_2012Metric_Pad1.15x1.40mm_HandSolder
J4: JTAG; PinHeader_1x05_P2.54mm_Horizontal
J5: DEBUG_UART; PinHeader_1x03_P2.54mm_Horizontal
R14, R18, R19, R20, R21, R22: 10K; R_0603_1608Metric_Pad0.98x0.95mm_HandSolder
R15, R17: 220; R_0603_1608Metric_Pad0.98x0.95mm_HandSolder
U2: PIC18F27K42-xSO; SOIC-28W_7.5x17.9mm_P1.27mm

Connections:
+3.3V: C19.1, C20.1, J4.4, R14.2, R18.2, R19.2, R20.2, R21.2, R22.2, U2.20 (VDD); also elsewhere on the board
/Keys/KEY_A: U2.5 (RA3); also elsewhere on the board
/Keys/KEY_B: U2.4 (RA2); also elsewhere on the board
/Keys/KEY_C: U2.3 (RA1); also elsewhere on the board
/Keys/KEY_D: U2.2 (RA0); also elsewhere on the board
/Keys/KEY_DOWN: U2.10 (RA6/OSC2_CLKOUT); also elsewhere on the board
/Keys/KEY_LEFT: U2.7 (RA5); also elsewhere on the board
/Keys/KEY_MENU: U2.26 (RB5); also elsewhere on the board
/Keys/KEY_RIGHT: U2.6 (RA4); also elsewhere on the board
/Keys/KEY_UP: U2.9 (RA7/OSC1_CLKIN); also elsewhere on the board
/Microcontroller/BATTERY_MEASURE: U2.24 (RB3); also elsewhere on the board
/Microcontroller/BUZZER: U2.13 (RC2); also elsewhere on the board
/Microcontroller/DISPLAY_DC: U2.23 (RB2); also elsewhere on the board
/Microcontroller/PGC: J4.1, U2.27 (RB6/PGC)
/Microcontroller/PGD: J4.2, U2.28 (RB7/PGD)
/Microcontroller/SPI_MISO: R20.1, U2.15 (RC4); also elsewhere on the board
/Microcontroller/SPI_MOSI: R22.1, U2.16 (RC5); also elsewhere on the board
/Microcontroller/SPI_SCLK: U2.14 (RC3); also elsewhere on the board
/Microcontroller//DISPLAY_RESET: U2.22 (RB1); also elsewhere on the board
/Microcontroller//SD_CARD_DETECT: R21.1, U2.25 (RB4); also elsewhere on the board
/Microcontroller//SPI_SS_DISPLAY: R19.1, U2.12 (RC1/SOSCI); also elsewhere on the board
/Microcontroller//SPI_SS_SD_CARD: R18.1, U2.11 (RC0/SOSCO); also elsewhere on the board
GND: C18.2, C19.2, C20.2, D1.1 (K), J4.3, J5.1, U2.8 (VSS), U2.19 (VSS); also elsewhere on the board
unnamed: D1.2 (A), R17.2
unnamed: C18.1, J4.5, R14.1, R15.1
unnamed: J5.2, U2.18 (RC7)
unnamed: J5.3, U2.17 (RC6)
unnamed: R17.1, U2.21 (RB0)
unnamed: R15.2, U2.1 (~MCLR/VPP/RE3)

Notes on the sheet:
Pin 2 : RX Pin 3 : TX

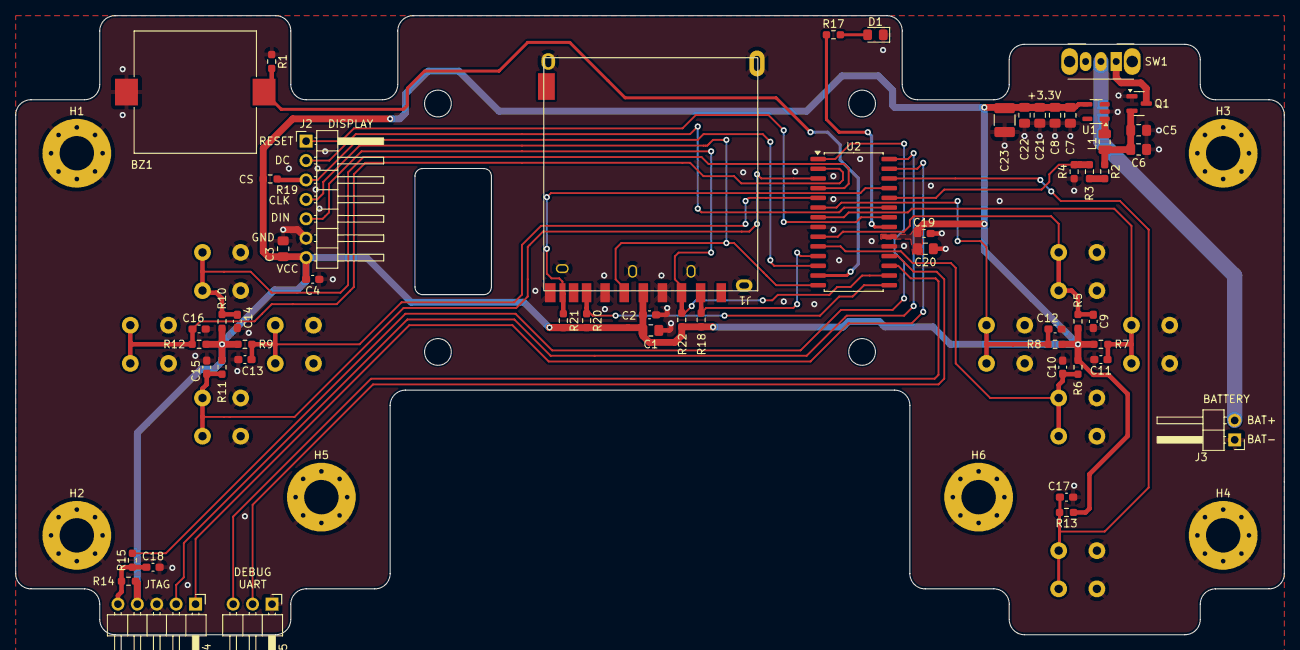
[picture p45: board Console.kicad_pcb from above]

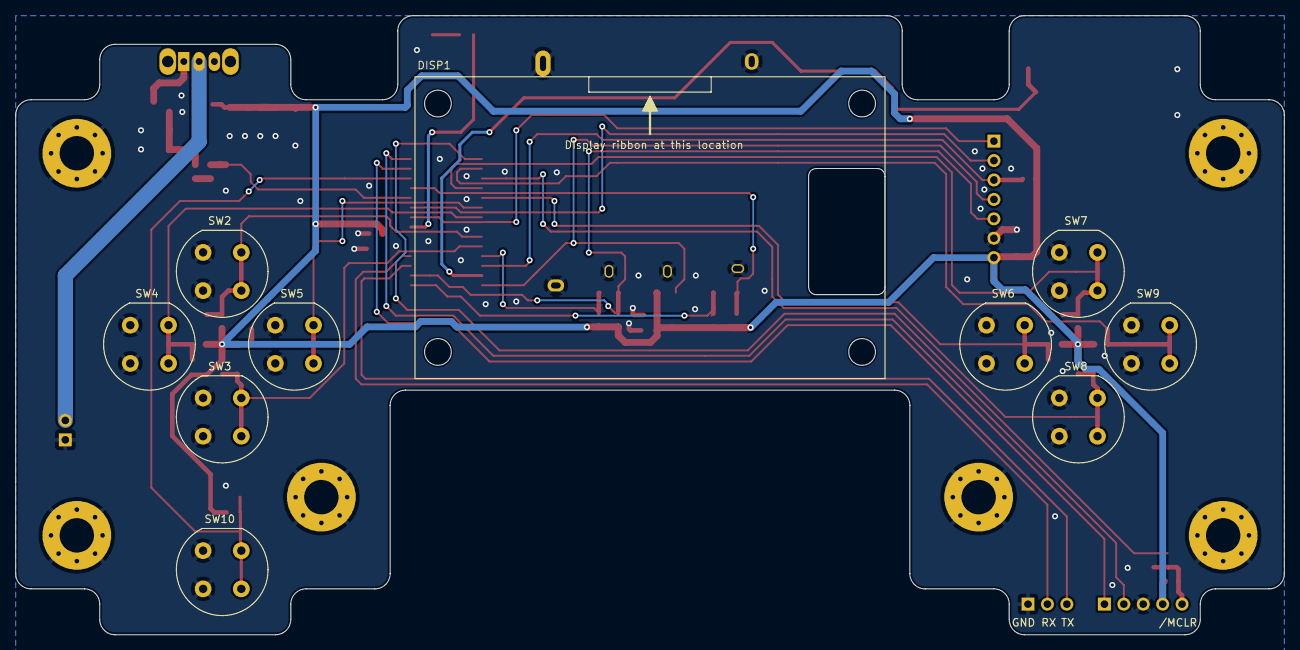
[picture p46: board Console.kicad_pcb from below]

Board: 2 copper layers, 166.0 x 81.0 mm, 72 parts (10 on the bottom side), 34 nets.

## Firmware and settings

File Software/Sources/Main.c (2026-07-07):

/** @file Main.c
 * Entry point and main loop for the Chip-8 Console.
 * @author Adrien RICCIARDI
 */
#include <Battery.h>
#include <Display.h>
#include <EEPROM.h>
#include <FAT.h>
#include <INI_Parser.h>
#include <Interpreter.h>
#include <Keyboard.h>
#include <LED.h>
#include <Localized_String.h>
#include <Log.h>
#include <MBR.h>
#include <NCO.h>
#include <SD_Card.h>
#include <Serial_Port.h>
#include <Shared_Buffer.h>
#include <Sound.h>
#include <SPI.h>
#include <stdio.h>
#include <string.h>
#include <Video_Player.h>
#include <xc.h>

//-------------------------------------------------------------------------------------------------
// Microcontroller configuration
//-------------------------------------------------------------------------------------------------
// CONFIG1L register
#pragma config RSTOSC = HFINTOSC_64MHZ, FEXTOSC = OFF  // Use the internal oscillator at 64MHz on reset, disable external oscillator
// CONFIG1H register
#pragma config FCMEN = OFF, CSWEN = ON, PR1WAY = OFF, CLKOUTEN = OFF // Disable Fail-Safe Clock Monitor, allow writing to the OSCCON register to change the oscillator settings, allow the DMA priority bit PRLOCK to be written several times, disable the CLKOUT feature
// CONFIG2L register
#pragma config BOREN = SBORDIS, LPBOREN = OFF, IVT1WAY = OFF, MVECEN = ON, PWRTS = PWRT_64, MCLRE = EXTMCLR // Always enable the Brown-out Reset, disable Low Power Brown-out Reset, IVTLOCK bit can be cleared and set repeatedly, enable interrupts vector table, configure the Power-up timer to 64ms, enable /MCLR
// CONFIG2H register
#pragma config XINST = OFF, DEBUG = OFF, STVREN = ON, PPS1WAY = OFF, ZCD = OFF, BORV = VBOR_2P7 // Disable Extended Instruction Set (it is not yet supported by the compiler), disable the Background debugger, reset on stack overflow or underflow, PPSLOCK bit can be set and cleared repeatedly, disable the unused Zero-cross Detection module, set the Brown-out voltage to the highest voltage at which the core can safely operate with a 64MHz clock
// CONFIG3L register
#pragma config WDTE = OFF // Disable the Watchdog timer
// CONFIG3H register
#pragma config WDTCCS = SC, WDTCWS = WDTCWS_7 // Set default values (all '1') as the watchdog timer is not used
// CONFIG4L register
#pragma config WRTAPP = OFF, SAFEN = OFF, BBEN = OFF // Allow writing to the Application Block, disable the Storage Area Flash, disable the Boot Block
// CONFIG4H register
#pragma config LVP = ON, WRTSAF = OFF, WRTD = OFF, WRTC = ON, WRTB = OFF // Enable Low-Voltage Programming to avoid needing to apply a high voltage on the /MCLR pin during programming, Storage Area Flash is not write-protected, Data EEPROM is not write-protected, Configuration Registers are write-protected, Boot Block is not write-protected
// CONFIG5L
#pragma config CP = OFF // Disable program and data code protection

//-------------------------------------------------------------------------------------------------
// Private constants
//-------------------------------------------------------------------------------------------------
/** Set to 1 to enable the log messages, set to 0 to disable them. */
#define MAIN_IS_LOGGING_ENABLED 1

/** The configuration file name on the SD card. */
#define MAIN_CONFIGURATION_FILE_NAME "CONFIG.INI"

/** How many measures to compute the average on. */
#define MAIN_BATTERY_SAMPLES_COUNT 8

/** Automatically append the "-DEBUG" prefix to the firmware version displayed into the Information menu if the firmware has been built with the debug mode, otherwise do not alter the firmware version. */
#ifdef LOG_IS_ENABLED
	#define MAIN_FIRMWARE_VERSION_DEBUG_FLAG_SUFFIX "-DEBUG"
#else
	#define MAIN_FIRMWARE_VERSION_DEBUG_FLAG_SUFFIX "\n"
#endif

//-------------------------------------------------------------------------------------------------
// Private variables
//-------------------------------------------------------------------------------------------------
/** The splash screen image displayed at console boot. */
const unsigned char Main_Splash_Screen[] =
{
	0x00, 0x00, 0x00, 0x00, 0x00, 0x00, 0x00, 0x00, 0x00, 0x00, 0x00, 0x00, 0x00, 0x00, 0x00, 0x00,
	0x00, 0x00, 0x00, 0x00, 0x00, 0x00, 0x00, 0x00, 0x00, 0x00, 0x00, 0x00, 0x00, 0x00, 0x00, 0x00,
	0x00, 0x00, 0x00, 0x00, 0x00, 0x00, 0x00, 0x00, 0x00, 0x00, 0x00, 0x00, 0x00, 0x00, 0x00, 0x00,
	0x00, 0x00, 0x00, 0x00, 0x00, 0x00, 0x00, 0x00, 0x00, 0x00, 0x00, 0x00, 0x00, 0x00, 0x00, 0x00,
	0x00, 0x00, 0x00, 0x00, 0x00, 0x00, 0x00, 0x00, 0x00, 0x00, 0x00, 0x00, 0x00, 0x00, 0x00, 0x00,
	0x00, 0x00, 0x00, 0x00, 0x00, 0x00, 0x00, 0x00, 0x00, 0x00, 0x00, 0x00, 0x00, 0x00, 0x00, 0x00,
	0x00, 0x00, 0x00, 0x00, 0x00, 0x00, 0x00, 0x00, 0x00, 0x00, 0x00, 0x00, 0x00, 0x00, 0x00, 0x00,
	0x00, 0x00, 0x00, 0x00, 0x00, 0x00, 0x00, 0x00, 0x00, 0x00, 0x00, 0x00, 0x00, 0x00, 0x00, 0x00,
	0x00, 0x00, 0x00, 0x00, 0x00, 0x00, 0x00, 0x00, 0x00, 0x00, 0x00, 0x00, 0x00, 0x00, 0x00, 0x00,
	0x00, 0x00, 0x00, 0x00, 0x00, 0x00, 0x00, 0x00, 0x00, 0x00, 0x00, 0x00, 0x00, 0x00, 0x00, 0x00,
	0x00, 0x00, 0x00, 0x00, 0x00, 0x00, 0x00, 0x00, 0x00, 0x00, 0x00, 0x00, 0x00, 0x00, 0x00, 0x00,
	0x00, 0x00, 0x00, 0x00, 0x00, 0x00, 0x00, 0x00, 0x00, 0x00, 0x00, 0x00, 0x00, 0x00, 0x00, 0x00,
	0x00, 0x00, 0x00, 0x00, 0x00, 0x00, 0x00, 0x00, 0x00, 0x00, 0x00, 0x00, 0x00, 0x00, 0x00, 0x00,
	0x00, 0xFF, 0xFF, 0xC0, 0x00, 0x00, 0x00, 0x00, 0x00, 0x00, 0x00, 0x00, 0x00, 0x1F, 0xFE, 0x00,
	0x01, 0xFF, 0xFF, 0xC0, 0x00, 0x00, 0x00, 0x00, 0x00, 0x00, 0x00, 0x00, 0x00, 0x7F, 0xFF, 0x80,
	0x01, 0xFF, 0xFF, 0xC0, 0x00, 0x00, 0x00, 0x00, 0x00, 0x00, 0x00, 0x00, 0x00, 0xFF, 0xFF, 0xC0,
	0x01, 0xFF, 0xFF, 0xC0, 0x00, 0x00, 0x00, 0x00, 0x00, 0x00, 0x00, 0x00, 0x01, 0xFF, 0xFF, 0xC0,
	0x01, 0xE0, 0x00, 0x00, 0x78, 0x01, 0xC0, 0x78, 0x0F, 0xFF, 0x80, 0x00, 0x01, 0xF0, 0x03, 0xE0,
	0x01, 0xE0, 0x00, 0x00, 0x78, 0x01, 0xC0, 0x78, 0x0F, 0xFF, 0xC0, 0x00, 0x01, 0xE0, 0x01, 0xE0,
	0x01, 0xE0, 0x00, 0x00, 0x78, 0x01, 0xC0, 0x78, 0x0F, 0xFF, 0xE0, 0x00, 0x01, 0xE0, 0x01, 0xE0,
	0x01, 0xE0, 0x00, 0x00, 0x78, 0x01, 0xC0, 0x78, 0x0F, 0x00, 0xF0, 0x00, 0x01, 0xE0, 0x01, 0xE0,
	0x01, 0xE0, 0x00, 0x00, 0x78, 0x01, 0xC0, 0x78, 0x0F, 0x00, 0x70, 0x00, 0x01, 0xF0, 0x03, 0xC0,
	0x01, 0xE0, 0x00, 0x00, 0x78, 0x01, 0xC0, 0x78, 0x0F, 0x00, 0x70, 0x00, 0x00, 0xFF, 0xFF, 0xC0,
	0x01, 0xE0, 0x00, 0x00, 0x78, 0x01, 0xC0, 0x78, 0x0F, 0x00, 0x70, 0x00, 0x00, 0xFF, 0xFF, 0xC0,
	0x01, 0xE0, 0x00, 0x00, 0x7F, 0xFF, 0xC0, 0x78, 0x0F, 0x00, 0xF0, 0xFF, 0x80, 0xFF, 0xFF, 0xC0,
	0x01, 0xE0, 0x00, 0x00, 0x7F, 0xFF, 0xC0, 0x78, 0x0F, 0x7F, 0xE0, 0xFF, 0x81, 0xF0, 0x03, 0xE0,
	0x01, 0xE0, 0x00, 0x00, 0x7F, 0xFF, 0xC0, 0x78, 0x0F, 0x7F, 0xE0, 0xFF, 0x81, 0xE0, 0x01, 0xE0,
	0x01, 0xE0, 0x00, 0x00, 0x78, 0x01, 0xC0, 0x78, 0x0F, 0x7F, 0x80, 0x00, 0x01, 0xE0, 0x01, 0xE0,
	0x01, 0xE0, 0x00, 0x00, 0x78, 0x01, 0xC0, 0x78, 0x0F, 0x00, 0x00, 0x00, 0x01, 0xE0, 0x01, 0xE0,
	0x01, 0xE0, 0x00, 0x00, 0x78, 0x01, 0xC0, 0x78, 0x0F, 0x00, 0x00, 0x00, 0x01, 0xF0, 0x03, 0xE0,
	0x01, 0xFF, 0xFF, 0xC0, 0x78, 0x01, 0xC0, 0x78, 0x0F, 0x00, 0x00, 0x00, 0x00, 0xFF, 0xFF, 0xC0,
	0x01, 0xFF, 0xFF, 0xE0, 0x78, 0x01, 0xC0, 0x78, 0x0F, 0x00, 0x00, 0x00, 0x00, 0xFF, 0xFF, 0xC0,
	0x01, 0xFF, 0xFF, 0xE0, 0x78, 0x01, 0xC0, 0x78, 0x0F, 0x00, 0x00, 0x00, 0x00, 0x7F, 0xFF, 0x80,
	0x00, 0xFF, 0xFF, 0xC0, 0x78, 0x01, 0xC0, 0x78, 0x0F, 0x00, 0x00, 0x00, 0x00, 0x1F, 0xFE, 0x00,
	0x00, 0x00, 0x00, 0x00, 0x00, 0x00, 0x00, 0x00, 0x00, 0x00, 0x00, 0x00, 0x00, 0x00, 0x00, 0x00,
	0x00, 0x00, 0x00, 0x00, 0x00, 0x00, 0x00, 0x00, 0x00, 0x00, 0x00, 0x00, 0x00, 0x00, 0x00, 0x00,
	0x00, 0x00, 0x00, 0x00, 0x00, 0x00, 0x00, 0x00, 0x00, 0x00, 0x00, 0x00, 0x00, 0x00, 0x00, 0x00,
	0x00, 0x00, 0x00, 0x00, 0x00, 0x00, 0x00, 0x00, 0x00, 0x00, 0x00, 0x00, 0x00, 0x00, 0x00, 0x00,
	0x00, 0x00, 0x00, 0x00, 0x00, 0x00, 0x00, 0x00, 0x00, 0x00, 0x00, 0x00, 0x00, 0x00, 0x00, 0x00,
	0x00, 0x00, 0x00, 0x00, 0x00, 0x00, 0x00, 0x00, 0x00, 0x00, 0x00, 0x00, 0x00, 0x00, 0x00, 0x00,
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
};

//-------------------------------------------------------------------------------------------------
// Private functions
//-------------------------------------------------------------------------------------------------
/** Program the EEPROM relevant locations with the default values. */
static void MainInitializeEEPROM(void)
{
	unsigned char i;

	// Do nothing if the EEPROM already contains data
	if (EEPROMReadByte(EEPROM_ADDRESS_IS_MEMORY_CONTENT_INITIALIZED) == 1)
	{
		LOG(MAIN_IS_LOGGING_ENABLED, "EEPROM content is already initialized, skipping initialization.");
		return;
	}
	LOG(MAIN_IS_LOGGING_ENABLED, "EEPROM is erased, starting the initialization process...");

	// Set the maximum sound level
	EEPROMWriteByte(EEPROM_ADDRESS_SOUND_LEVEL_PERCENTAGE, EEPROM_SOUND_LEVEL_PERCENTAGE_HIGH);

	// Set the maximum display brightness
	EEPROMWriteByte(EEPROM_ADDRESS_DISPLAY_BRIGHTNESS, EEPROM_DISPLAY_BRIGHTNESS_HIGH);

	// Clear all non-volatile storage registers of the Super-Chip 8 interpreter
	for (i = 0; i < INTERPRETER_FLAG_REGISTERS_COUNT; i++) EEPROMWriteByte(EEPROM_ADDRESS_INTERPRETER_FLAG_REGISTER_0 + i, 0);

	// Set the default language to English
	EEPROMWriteByte(EEPROM_ADDRESS_SYSTEM_LANGUAGE, LOCALIZED_STRING_LANGUAGE_ID_ENGLISH);

	// Tell that the EEPROM is initialized
	EEPROMWriteByte(EEPROM_ADDRESS_IS_MEMORY_CONTENT_INITIALIZED, 1);
	LOG(MAIN_IS_LOGGING_ENABLED, "EEPROM content has been successfully initialized.");
}

/** Display the main menu with the battery charge that is automatically updated.
 * @return A keys mask with the allowed key pressed by the user.
 */
static TKeyboardKey MainDisplayMainMenu(void)
{
	unsigned char Battery_Charge_Samples[MAIN_BATTERY_SAMPLES_COUNT], Battery_Charge, Keys_Mask, i, Sample_Index = 0, Ticks_Counter_Samples = 0, Ticks_Counter_Show_Menu;
	unsigned short Mean;

	// Initialize all the samples with the current battery value
	for (i = 0; i < MAIN_BATTERY_SAMPLES_COUNT; i++) Battery_Charge_Samples[i] = BatteryGetCurrentChargePercentage();

	// Display the main menu until an allowed key is pressed
	Ticks_Counter_Show_Menu = 250; // Set the counter to its expiring value, so the menu is immediately displayed when the function is called
	do
	{
		// Increment the ticks counters (no need for a real time accuracy here)
		if (NCO_IS_TICK_ELAPSED())
		{
			Ticks_Counter_Samples++;
			Ticks_Counter_Show_Menu++;
			NCO_CLEAR_TICK_INTERRUPT_FLAG();
		}

		// Each ~1s, sample a new battery value
		if (Ticks_Counter_Samples >= (1000 / 16))
		{
			Battery_Charge_Samples[Sample_Index] = BatteryGetCurrentChargePercentage();
			Sample_Index++;
			if (Sample_Index >= MAIN_BATTERY_SAMPLES_COUNT) Sample_Index = 0;
			Ticks_Counter_Samples = 0;
		}

		// Each ~4s, display the menu with an updated battery charge value
		if (Ticks_Counter_Show_Menu >= (4000 / 16))
		{
			Mean = 0;
			for (i = 0; i < MAIN_BATTERY_SAMPLES_COUNT; i++) Mean += Battery_Charge_Samples[i];
			Mean /= MAIN_BATTERY_SAMPLES_COUNT;

			snprintf(Shared_Buffers.String_Temporary, sizeof(Shared_Buffers.String_Temporary), LocalizedStringGet(LOCALIZED_STRING_ID_MAIN_MENU_VIEW_CONTENT), Mean);
			DisplayDrawTextMessage(Shared_Buffer_Display, LocalizedStringGet(LOCALIZED_STRING_ID_MAIN_MENU_VIEW_TITLE), Shared_Buffers.String_Temporary);
			Ticks_Counter_Show_Menu = 0;
		}

		Keys_Mask = KeyboardReadKeysMask();
	} while ((Keys_Mask & (KEYBOARD_KEY_A | KEYBOARD_KEY_B | KEYBOARD_KEY_C | KEYBOARD_KEY_D)) == 0);

	// Clear the menu key press event to avoid the following menus to detect a spurious event
	KeyboardIsMenuKeyPressed();

	return Keys_Mask;
}

/** Probe the SD card and mount the first FAT partition.
 * @return 0 if the SD card was not removed since the last time it was probed,
 * @return 1 if the SD card was removed since the last time it was probed.
 */
static unsigned char MainMountSDCard(void)
{
	TMBRPartitionData Partitions_Data[MBR_PRIMARY_PARTITIONS_COUNT], *Pointer_Partitions_Data;
	unsigned char i, Is_Message_Displayed;
	TSDCardDetectionStatus Card_Detection_Status;

	// Wait for an SD card to be inserted
Detect_SD_Card:
	Is_Message_Displayed = 0;
	while (1)
	{
		Card_Detection_Status = SDCardGetDetectionStatus();
		if (Card_Detection_Status != SD_CARD_DETECTION_STATUS_NO_CARD) break;

		// Avoid redrawing the message at each loop
		if (!Is_Message_Displayed)
		{
			DisplayDrawTextMessage(Shared_Buffer_Display, LocalizedStringGet(LOCALIZED_STRING_ID_SD_CARD_MESSAGE_TITLE), LocalizedStringGet(LOCALIZED_STRING_ID_SD_CARD_MESSAGE_INSERT_SD_CARD_CONTENT));
			Is_Message_Displayed = 1;
		}
	}

	// The card has not changed and was already probed, nothing more to do
	if (Card_Detection_Status == SD_CARD_DETECTION_STATUS_DETECTED_NOT_REMOVED)
	{
		LOG(MAIN_IS_LOGGING_ENABLED, "The card has not changed and was already probed.");
		return 0;
	}

	// Probe the SD card
	if (SDCardProbe() != 0)
	{
		LOG(MAIN_IS_LOGGING_ENABLED, "\033[31mFailed to probe the SD card.\033[0m");
		DisplayDrawTextMessage(Shared_Buffer_Display, LocalizedStringGet(LOCALIZED_STRING_ID_SD_CARD_MESSAGE_TITLE), LocalizedStringGet(LOCALIZED_STRING_ID_SD_CARD_MESSAGE_PROBE_ERROR_CONTENT));
		while (!KeyboardIsMenuKeyPressed());
		__delay_ms(1000); // Give some time to the SD card to wake up
		goto Detect_SD_Card;
	}

	// The first SD card block contains the MBR, get it
	if (SDCardReadBlock(0, Shared_Buffers.Buffer) != 0)
	{
		LOG(MAIN_IS_LOGGING_ENABLED, "Failed to read the SD card MBR block.");
		DisplayDrawTextMessage(Shared_Buffer_Display, LocalizedStringGet(LOCALIZED_STRING_ID_SD_CARD_MESSAGE_TITLE), LocalizedStringGet(LOCALIZED_STRING_ID_SD_CARD_MESSAGE_MBR_READ_ERROR_CONTENT));
		while (!KeyboardIsMenuKeyPressed());
		__delay_ms(1000); // Give some time to the SD card to wake up
		goto Detect_SD_Card;
	}

	// Find the first valid primary partitions (do not care about the partition type, as it does not reflect the real file system the partition is formatted with)
	MBRParsePrimaryPartitions(Shared_Buffers.Buffer, Partitions_Data);
	for (i = 0; i < MBR_PRIMARY_PARTITIONS_COUNT; i++)
	{
		// Cache the partition data access
		Pointer_Partitions_Data = &Partitions_Data[i];
		LOG(MAIN_IS_LOGGING_ENABLED, "Partition %d : type=0x%02X, start sector=%lu, sectors count=%lu.", i + 1, Pointer_Partitions_Data->Type, Pointer_Partitions_Data->Start_Sector, Pointer_Partitions_Data->Sectors_Count);

		// Bypass any empty partition
		if (Pointer_Partitions_Data->Type == 0)
		{
			LOG(MAIN_IS_LOGGING_ENABLED, "Partition is empty, trying next one.");
			continue;
		}

		// Try to mount the file system as the partition is not empty
		if (FATMount(Pointer_Partitions_Data, Shared_Buffers.Buffer) != 0)
		{
			LOG(MAIN_IS_LOGGING_ENABLED, "Failed to mount the partition %d.", i + 1);
			continue;
		}
		LOG(MAIN_IS_LOGGING_ENABLED, "Partition %d was successfully mounted.", i + 1);
		break;
	}
	// Were all partitions invalid ?
	if (i == MBR_PRIMARY_PARTITIONS_COUNT)
	{
		LOG(MAIN_IS_LOGGING_ENABLED, "No valid partition could be found.");
		DisplayDrawTextMessage(Shared_Buffer_Display, LocalizedStringGet(LOCALIZED_STRING_ID_SD_CARD_MESSAGE_TITLE), LocalizedStringGet(LOCALIZED_STRING_ID_SD_CARD_MESSAGE_NO_VALID_PARTITION_ERROR_CONTENT));
		while (!KeyboardIsMenuKeyPressed());
		goto Detect_SD_Card;
	}

	// The SD card has been removed since last time it was probed
	return 1;
}
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
void main(void)
{
	char *Pointer_String_Game_INI_Section;
	unsigned char Is_SD_Card_Removed, Last_Played_Game_Index = 0;
	unsigned short Configuration_File_Size;
	TKeyboardKey Keys_Mask;

	// Wait for the internal oscillator to stabilize
	while (!OSCSTATbits.HFOR);

	// Gate all peripheral clocks to save some power, each used peripheral will then be selectively re-enabled
	PMD0 = 0x7F; // Keep the system clock network enabled
	PMD1 = 0xFF;
	PMD2 = 0xFF;
	PMD3 = 0xFF;
	PMD4 = 0xFF;
	PMD5 = 0xFF;
	PMD6 = 0xFF;
	PMD7 = 0xFF;

	// Initialize all needed modules
	LEDInitialize();
	LED_SET_ENABLED(1); // Turn the LED on during the microcontroller boot
	SerialPortInitialize();
	LogInitialize(); // The log module needs the serial port to be working
	#if MAIN_IS_LOGGING_ENABLED
		MainCheckResetReason(); // Right after the logs are working to display the results, determine if there was an abnormal reset
	#endif
	EEPROMInitialize();
	MainInitializeEEPROM(); // Initialize the EEPROM content if the microcontroller EEPROM area is not yet programmed
	LocalizedStringInitialize(); // Initialize the localized strings as soon as the EEPROM is ready, so any following module that encounter an error can display a localized message
	NCOInitialize();
	SoundInitialize();
	KeyboardInitialize();
	InterpreterInitialize();
	SDCardInitialize();
	SPIInitialize(); // The SPI module must be initialized before the display
	DisplayInitialize();
	SDCardInitialize();
	BatteryInitialize();

	// Generate a 60Hz tick for the main menu
	NCOConfigure(NCO_TICK_FREQUENCY_INTERPRETER);

	// Show the splash screen
	memcpy(Shared_Buffer_Display, Main_Splash_Screen, sizeof(Shared_Buffer_Display));
	DisplayDrawFullSizeBuffer(Shared_Buffer_Display);
	__delay_ms(2000);

	// Initialize the interrupts
	// Set the vector table base address to the default value
	IVTBASEU = 0;
	IVTBASEH = 0;
	IVTBASEL = 0x08;
	// Enable interrupts
	INTCON0bits.IPEN = 0; // Disable priority, all interrupts are high-priority and use the hardware order
	INTCON0bits.GIE = 1; // Enable all interrupts

	// The boot was completed, turn the LED off to same some power
	LED_SET_ENABLED(0);

	while (1)
	{
		// Main menu
		Keys_Mask = MainDisplayMainMenu();

		// Games
		if (Keys_Mask & KEYBOARD_KEY_A)
		{
			// Load the games configuration from the SD card
			while (1)
			{
				// Block until an SD card with a valid FAT file system is inserted
				Is_SD_Card_Removed = MainMountSDCard();

				// Block until a valid configuration file is found
				if (MainLoadConfigurationFile(&Configuration_File_Size) != 0) continue;

				// Block until a game is found
				if (Is_SD_Card_Removed) Last_Played_Game_Index = 0; // Restart displaying the game selection menu from the first one if the card has been changed, as we do not know its content
				Pointer_String_Game_INI_Section = MainSelectGame(Configuration_File_Size, &Last_Played_Game_Index);
				if (Pointer_String_Game_INI_Section == NULL) break; // Return to main menu if the player wanted chose to, or if an error occurred

				// Try to load the game from the SD card
				if (InterpreterLoadProgramFromFile(Pointer_String_Game_INI_Section) != 0)
				{
					LOG(MAIN_IS_LOGGING_ENABLED, "Could not load the selected game.");
					DisplayDrawTextMessage(Shared_Buffer_Display, LocalizedStringGet(LOCALIZED_STRING_ID_SD_CARD_MESSAGE_TITLE), LocalizedStringGet(LOCALIZED_STRING_ID_SD_CARD_MESSAGE_GAME_LOADING_ERROR_CONTENT));
					while (!KeyboardIsMenuKeyPressed());
					continue;
				}
				LOG(MAIN_IS_LOGGING_ENABLED, "The game was successfully loaded.");

				// Generate a 60Hz frequency for the sound module and the frame rate rendering
				NCOConfigure(NCO_TICK_FREQUENCY_INTERPRETER);

				// Execute the program, when exiting the NCO is still configured at 60Hz
				InterpreterRunProgram();
			}
		}
		// Video player
		else if (Keys_Mask & KEYBOARD_KEY_B)
		{
			// TODO
			MainMountSDCard();

			// Generate a 25Hz tick for the frames rendering
			NCOConfigure(NCO_TICK_FREQUENCY_VIDEO_PLAYER);

			VideoPlayer();

			// Generate a 60Hz tick for the main menu
			NCOConfigure(NCO_TICK_FREQUENCY_INTERPRETER);
		}
		// Settings
		else if (Keys_Mask & KEYBOARD_KEY_C) MainDisplaySettingsMenu();
		// Information
		else if (Keys_Mask & KEYBOARD_KEY_D)
		{
			snprintf(Shared_Buffers.String_Temporary, sizeof(Shared_Buffers.String_Temporary), LocalizedStringGet(LOCALIZED_STRING_ID_INFORMATION_MENU_VIEW_CONTENT), MAKEFILE_FIRMWARE_VERSION MAIN_FIRMWARE_VERSION_DEBUG_FLAG_SUFFIX, __DATE__, __TIME__);
			DisplayDrawTextMessage(Shared_Buffer_Display, LocalizedStringGet(LOCALIZED_STRING_ID_INFORMATION_MENU_VIEW_TITLE), Shared_Buffers.String_Temporary);

			// Wait for the 'back' key to be pressed
			KeyboardWaitForKeys(KEYBOARD_KEY_MENU);
		}
	}
}

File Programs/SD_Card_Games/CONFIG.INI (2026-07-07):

[0]
Title=Brix
Description=by Andreas Gustafsson
ROMFile=BRIX.CH8
KeyValueLeft=4
KeyValueRight=6
DisplayWrapping=1

[0]
Title=Slippery Slope
Description=By John Earnest
ROMFile=SLIPSLOP.CH8
KeyValueUp=5
KeyValueDown=8
KeyValueLeft=7
KeyValueRight=9
KeyValueA=6

[0]
Title=Cavern
Description=By Matthew Mikolay
ROMFile=CAVERN.CH8
FastRendering=1
KeyValueUp=2
KeyValueDown=8
KeyValueLeft=4
KeyValueRight=6
KeyValueA=0
KeyValueB=1
KeyValueC=5
KeyValueD=3

[0]
Title=Chipquarium
Description=By Matthew Mikolay
ROMFile=CHIPQUAR.CH8
KeyValueUp=2
KeyValueDown=8
KeyValueRight=11
KeyValueA=15
KeyValueB=14
KeyValueC=13
KeyValueD=12

[0]
Title=Blitz
Description=By John Earnest
ROMFile=BLITZ.CH8
FastRendering=1
KeyValueC=5

[0]
Title=Laser Defence
Description=By Kyle Saburao
ROMFile=LASERDEF.CH8
FastRendering=1
KeyValueUp=5
KeyValueDown=8
KeyValueLeft=7
KeyValueRight=9
KeyValueC=6

[0]
Title=Shooth3rd
Description=by Beholder
ROMFile=SHTH3RD.CH8
FastRendering=1
KeyValueUp=4
KeyValueDown=7
KeyValueLeft=5
KeyValueRight=8
KeyValueB=9
KeyValueC=6
KeyValueD=10

[0]
Title=Outlaw
Description=By John Earnest
ROMFile=OUTLAW.CH8
KeyValueUp=5
KeyValueDown=8
KeyValueLeft=7
KeyValueRight=9
KeyValueC=6
DisplayWrapping=1

[0]
Title=Minesweep8r
Description=By James Kohli
ROMFile=MINESWPR.CH8
KeyValueUp=5
KeyValueDown=8
KeyValueLeft=7
KeyValueRight=9
KeyValueA=4
KeyValueB=13
KeyValueC=6

[0]
Title=Snake
Description=By Timo Triisa
ROMFile=SNAKE.SC8
RenderingDelay=30
KeyValueUp=5
KeyValueDown=8
KeyValueLeft=7
KeyValueRight=9

[0]
Title=Rockto
Description=By SupSuper
ROMFile=ROCKTO.SC8
KeyValueUp=5
KeyValueDown=8
KeyValueLeft=7
KeyValueRight=9
KeyValueA=1

[0]
Title=Horsey Jump
Description=Unknown author
ROMFile=HORSJUMP.SC8
FastRendering=1
KeyValueC=0

[0]
Title=Hidden!
Description=By David Winter
ROMFile=HIDDEN.CH8
FastRendering=1
KeyValueUp=2
KeyValueDown=8
KeyValueLeft=4
KeyValueRight=6
KeyValueC=5

[0]
Title=Paddles
Description=Unknown author
ROMFile=PADDLES.CH8
KeyValueLeft=4
KeyValueRight=6
KeyValueA=7
KeyValueB=14
KeyValueC=15
KeyValueD=9

[0]
Title=Ant
Description=Unknown author
ROMFile=ANT.SC8
RenderingDelay=3
KeyValueLeft=3
KeyValueRight=12
KeyValueC=10

[0]
Title=Wordle
Description=By John Earnest
ROMFile=WDL.CH8
MemoryLoadStoreIncrement=1
ShiftUsingVy=1
KeyValueUp=5
KeyValueDown=8
KeyValueLeft=7
KeyValueRight=9
KeyValueA=4
KeyValueC=6
KeyValueD=15

[0]
Title=Super Octogon
Description=By John Earnest
ROMFile=OCTOGON.SC8
FastRendering=1
KeyValueA=7
KeyValueC=9

[0]
Title=3D VIP'r Maze
Description=By Timendus
ROMFile=3DVIPMAZ.SC8
FastRendering=1
KeyValueUp=5
KeyValueDown=8
KeyValueLeft=7
KeyValueRight=9

[0]
Title=Labyrinthine
Description=By Temp Var Studios
ROMFile=LABYRINE.CH8
FastRendering=1
KeyValueUp=5
KeyValueDown=8
KeyValueLeft=7
KeyValueRight=9

[0]
Title=SneakSurround
Description=By Tom Swan
ROMFile=SNKSURND.CH8
FastRendering=1
KeyValueUp=5
KeyValueDown=8
KeyValueLeft=7
KeyValueRight=9

[0]
Title=Enter the mine
Description=By tquester
ROMFile=ENTRMINE.SC8
RenderingDelay=3
MemoryLoadStoreIncrement=1
KeyValueLeft=7
KeyValueRight=9
KeyValueC=5

[0]
Title=Glitch Ghost
Description=By Jackie Kircher
ROMFile=GLITGHST.CH8
FastRendering=1
KeyValueUp=5
KeyValueDown=8
KeyValueLeft=7
KeyValueRight=9
KeyValueC=6

[0]
Title=Rush Hour
Description=By Hap
ROMFile=RUSHHOUR.CH8
FastRendering=1
KeyValueUp=5
KeyValueDown=8
KeyValueLeft=7
KeyValueRight=9
KeyValueB=1
KeyValueC=10

[0]
Title=Golf
Description=By Buffi
ROMFile=GOLF.CH8
FastRendering=1
ShiftUsingVy=1
MemoryLoadStoreIncrement=1
DisplayWrapping=1
KeyValueLeft=7
KeyValueRight=9
KeyValueC=5

[0]
Title=Clostro
Description=By jibbl
ROMFile=CLOSTRO.CH8
ShiftUsingVy=1
FastRendering=1
KeyValueUp=5
KeyValueDown=8
KeyValueLeft=7
KeyValueRight=9
KeyValueA=4
KeyValueC=6

[0]
Title=Black Rainbow
Description=By John Earnest
ROMFile=BLKRNBOW.CH8
FastRendering=1
KeyValueUp=5
KeyValueDown=8
KeyValueLeft=7
KeyValueRight=9
KeyValueC=0

[0]
Title=Octris
Description=By Sunil
ROMFile=OCTRIS.CH8
FastRendering=1
KeyValueUp=9
KeyValueDown=7
KeyValueRight=8
KeyValueB=13
KeyValueC=5

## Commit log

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2023-10-20 [Software] Used the Numerically Controlled Oscillator (NCO) to generate a 60Hz square wave to clock the sound and delay CHIP-8 timers.
    [Main.c]
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2023-10-27 [Software] Used some hardware tricks based on the Configurable Logic Cells to automatically turn off the buzzer when the CHIP-8 sound timer has elapsed.
    [Main.c, Sound.c]
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2024-01-07 [Software] Fixed the SD card ACMD41 initialization loop by using the correct timeout.
    [SD_Card.c]
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2024-01-20 [Software] Removed the SerialPortWriteLog() function as printf() can now be directly used.
    Also fixed some printf() format warnings now that the compiler seems to better understand the printf() usages.
    The generated code size with printf() is using about 11% of the program memory, while it was using about 20% with SerialPortWriteLog().
    [Main.c, Serial_Port.c]
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2024-02-18 [Software] Cleared the display data RAM on initialization to avoid displaying random pixels.
    [Display.c, Display.h]
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2024-03-19 [Software] Manually drove the display SPI /SS pin, this does not uses a lot more cycles and avoids a large amount of unneeded transitions.
    [Display.c, Main.c, SD_Card.c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]
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2024-04-04 [Software] Fixed a strange hardware-related bug getting the sound playing on console start until a sound was played.
    [Sound.c]
2024-04-10 [Hardware] Started the board schematic. Started designing the power supply.
    [Console.kicad_pcb, Console.kicad_sch, Power_Supply.kicad_sch]
2024-04-11 [Hardware] Switched project from KiCad 6 to KiCad 7.
    [Console.kicad_sch, Power_Supply.kicad_sch]
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2024-05-16 [Hardware] Added battery reverse polarity voltage protection and power switch.
    [Power_Supply.kicad_sch]
2024-05-17 [Hardware] Started designing the microcontroller sheet. Currently added the microcontroller power supply and JTAG.
    [Console.kicad_sch, Microcontroller.kicad_sch, Power_Supply.kicad_sch]
2024-05-17 [Hardware] Connected the keyboard keys to the microcontroller and added the buzzer.
    [Console.kicad_sch, Microcontroller.kicad_sch, Power_Supply.kicad_sch]
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2024-05-19 [Hardware] Added the SD card to the schematic.
    [Console.kicad_sch, Microcontroller.kicad_sch]
2024-05-19 [Hardware] Added the menu key, the debug LED and reorganized the key signals.
    [Console.kicad_sch, Keys.kicad_sch, Microcontroller.kicad_sch]
2024-05-26 [Hardware] Added the SD card detection feature.
    This can be useful if the SD card hot swapping feature needs to be supported one day.
    [Console.kicad_sch, Microcontroller.kicad_sch]
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2024-05-26 [Hardware] Added the display and the display connector to the schematic.
    [Console.kicad_sch]
2024-05-26 [Hardware] Added the battery voltage measurement to the schematic.
    [Console.kicad_sch, Microcontroller.kicad_sch, Power_Supply.kicad_sch]
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2024-05-26 [Hardware] Added the missing power supply to the SD card connector and specified the debug LED.
    [Console.kicad_sch, Microcontroller.kicad_sch]
2024-05-28 [Hardware] Assigned the battery connector footprint into the schematic.
    [Microcontroller.kicad_sch, Power_Supply.kicad_sch]
2024-05-29 [Hardware] Removed the transistor driving the debug LED.
    The LED current is about 5mA, so a microcontroller pin is enough to drive it.
    [Keys.kicad_sch, Microcontroller.kicad_sch]
2024-05-29 [Hardware] Replaced the battery measurement 270ohm resistor by a 560ohm one to have a bit more margin.
    [Power_Supply.kicad_sch]
2024-06-05 [Hardware] Added the CMT-1604-SMT-TR buzzer footprint and 3D model.
2024-06-05 [Hardware] Added the buzzer footprint to the buzzer symbol in the schematic.
    [Console.kicad_sch]
2024-06-05 [Hardware] Started the PCB routing. Initial components placement is in progress.
    [Console.kicad_pcb]
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2024-06-07 [Hardware] Placed all the mechanical parts and created the initial PCB cutting edges. Also added the mounting holes.
    [Console.kicad_pcb, Console.kicad_sch]
2024-06-07 [Hardware] Excluded the mounting holes from the bill of materials.
    [Console.kicad_sch]
2024-06-07 [Hardware] Moved the battery measurement voltage divider after the polarity inversion protection transistor.
    [Power_Supply.kicad_sch]
2024-06-08 [Hardware] Placed all the components on the PCB.
    [Console.kicad_pcb]
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2024-06-09 [Hardware] Routed the power supply, the keys and the connectors. The connections to the microcontroller are not made yet.
    [Console.kicad_pcb]
2024-06-09 [Hardware] Added the washers courtyard area on the OLED module footprint bottom side.
    [Console.kicad_pcb]
2024-06-10 [Hardware] Made PCB corners round to improve PCB cutting.
    [Console.kicad_pcb]
2024-06-10 [Hardware] Routed the right side of the microcontroller.
    [Console.kicad_pcb]
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2024-06-10 [Hardware] Added useful silkscreen information to the PCB.
    [Console.kicad_pcb]
2024-06-11 [Hardware] Positioned the components references on the PCB.
    [Console.kicad_pcb]
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2024-06-30 [Software] Changed the buzzer oscillation frequency to 4KHz to fit the console final hardware.
    [Sound.c]
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2024-06-30 [Hardware] Replaced the display cable color silkscreen prints close to connector J2 by the display signal names.
    [Console.kicad_pcb]
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2024-07-03 [Hardware] Increased the casing dimensions to better protect the PCB.
    [Console.kicad_pcb]
2024-07-03 [Casing] Added the beginning of the bottom plate sketch.
    [Casing.FCStd]
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2024-07-03 [Casing] Added the hex spacer holes to the bottom plate and the hex spacer parts.
    [Casing.FCStd]
2024-07-03 [Casing] Added the top plate sketch with the hex spacer holes.
    [Casing.FCStd]
2024-07-03 [Casing] Moved the appropriate sketch Z axis to their real location.
    [Casing.FCStd]
2024-07-03 [Casing] Added the button holes to the top plate.
    [Casing.FCStd]
2024-07-03 [Casing] Added the display cut to the top plate.
    [Casing.FCStd]
2024-07-03 [Casing] Decreased display hole dimensions because the display is not meant to go through the top plate anymore.
    [Casing.FCStd]
2024-07-03 [Casing] Added the PCB mounting holes to the bottom plate.
    [Casing.FCStd]
2024-07-03 [Casing] Added the top and bottom plates technical views.
    [Casing.FCStd]
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2024-07-06 [Software] Allowed to navigate through the games list in reverse order.
    [Main.c]
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2024-07-18 [Hardware] Allowed populating the buzzer reset resistor.
    [Console.kicad_sch]
2024-07-18 [Hardware] Depopulated the display connector as the display wires are directly soldered onto the board.
    [Console.kicad_pcb, Console.kicad_sch]
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2024-07-24 [Software] Made the Chip-8 DRW instruction collision more accurate when the sprite coordinates are not aligned with a frame buffer byte.
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2024-07-26 [Casing] Increased the button holes on the top plate from a 9.3mm diameter to 9.6mm diameter, so buttons are not rubbing against the plate.
    [Casing.FCStd]
2024-07-27 [Software] Removed old test code from the Main module.
    Also added the missing variable documentation for the MainLoadConfigurationFile() function.
    [Main.c]
2024-07-27 [Software] Added a debug feature displaying the causes of a system reset.
    [Main.c]
2024-07-27 [Software] Decreased the Brown-out threshold voltage to avoid spurious resets.
    The newly set threshold should be enough to make the core runs flawlessly when clocked at 64MHz.
    [Main.c]
2024-07-27 [Programs] Added the Slippery Slope game by John Earnest.
    [CONFIG.INI]
2024-07-27 [Software] Fixed some misspelling in the comments.
    [Display.c]
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2024-07-27 [Programs] Patched the Cavern game to avoid using the key code 2 twice (use the key code 5 instead for speed selection).
    [CONFIG.INI]
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2024-08-18 [Hardware] Moved the motherboard project to a dedicated directory to make some room for the battery hatch project.
    [Console.kicad_pcb, Console.kicad_sch, Keys.kicad_sch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]
2024-08-18 [Hardware] Added an empty project for the battery hatch.
    [Battery_Hatch.kicad_pcb, Battery_Hatch.kicad_sch]
2024-08-19 [Hardware] Created all battery hatch pieces in the PCB.
    [Battery_Hatch.kicad_pcb]
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2024-08-19 [Hardware] Created a panel with the battery hatch pieces.
    [Battery_Hatch.kicad_pcb]
2024-08-19 [Hardware] Increased a bit the battery hatch holes for the hinges to take into account the milling path.
    [Battery_Hatch.kicad_pcb]
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2024-08-30 [Hardware] Left more space for the battery pack by removing a part of the hinges.
    [Battery_Hatch.kicad_pcb]
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2024-08-31 [Programs] Added the Minesweep8r game by James Kohli.
    [CONFIG.INI]
2024-09-06 [Software] Disabled the serial port unused functions in production mode to avoid compilation warnings.
    [Serial_Port.c]
2024-09-15 [Software] Displayed an error message in case of virtual machine stack underflow.
2024-09-15 [Software] Displayed an error message in case of virtual machine stack overflow.
2024-11-04 [Programs] Added the Super-Chip BMP Viewer Flip-8 Logo demo program by Newsdee.
    [CONFIG.INI]
2025-02-16 [Hardware] Reduced the PCB area under the Menu button to make the PCB size identical to the area containing the debug pin headers.
    This prevents the user to touch the PCB with the fingers while using the console.
    [Console.kicad_pcb]
2025-03-08 [Software] Replaced the 'D' key by the 'Menu' key to exit the settings menu.
    [Main.c]
2025-03-08 [Software] Replaced the 'D' key by the 'Menu' key to exit the games menu.
    [Main.c]
2025-03-08 [Software] Replaced the 'D' key by the 'Menu' key to exit the information menu.
    [Main.c]
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2025-04-07 [Hardware] Moved the LED to the bottom side of the PCB, so it induces less backlight to the display.
    This also simplifies SMD assembly.
    [Console.kicad_pcb]
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2025-04-12 [Programs] Added the Glitch Ghost game by Jackie Kircher.
    [CONFIG.INI]
2025-04-12 [Hardware] Added an additional via to the PCB to better fill the ground plane.
    [Console.kicad_pcb]
2025-05-27 [Hardware] Added to the schematic more decoupling capacitors to the DC/DC output voltage.
    [Power_Supply.kicad_sch]
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2025-05-27 [Hardware] Updated some component footprints in the PCB to fix KiCad 9 warnings.
    [Console.kicad_pcb]
2025-06-02 [Software] Reorganized the functions return codes to always use the same ordering scheme.
    Also fixed some Doxygen warnings concerning some function arguments.
    [Main.c]
2025-06-02 [Software] Added some missing documentation to the SPI, FAT, interpreter and shared buffer modules.
2025-06-03 [Programs] Enabled the 'VF reset' quirk for the Timendus quirks test checking the Chip-8 compliance.
    [CONFIG.INI]
2025-06-29 [Programs] Made a little improvement to the Wordle game : added an additional key to validate a word, to avoid the need of selecting the 'enter' location every time.
    [CONFIG.INI]
2025-06-29 [Programs] Reattributed the Wordle game to the correct author.
    [CONFIG.INI]
2025-07-09 Added to the README.md the pictures of the PCB supports replacement.
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2026-01-31 [Software] Started the video player implementation.
    It is currently able to load a fixed file and play it with fixed frame rate.
    [Main.c]
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2026-02-05 [Software] Fixed the NCO frequency computations by using the correct MFINTOSC/4 frequency.
    Also renamed the NCO_TICK_FREQUENCY_xxx constants to abstract the frequencies, as we are sometime caring about a square wave generation and sometimes just a delay.
    [Main.c]
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2026-03-04 [Hardware] Added the missing copper to edge PCB clearance.
    [Console.kicad_pcb]
2026-04-12 [Software] Cleared the Menu key flag before displaying a main menu sub-menu.
    This prevents the sub-menu from detecting a spurious Menu key press and exiting immediately.
    [Main.c]
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2026-11-13 [Hardware] Fixed the "power pin not driven" ERC errors in the schematic.
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
